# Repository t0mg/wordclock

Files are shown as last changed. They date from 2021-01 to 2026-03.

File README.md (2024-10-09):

# Wordclock
ESP32 based DIY wordclock project

TL;DR: check out this :sparkles:[demo video](https://youtu.be/WF_X5soabm0) :sparkles:

<br/>
Another take on the classic DIY word clock. This one requires a laser cutter but promises a very clean result and is quite cheap to make (about 50 €) while being feature packed with its 11x10 RGB LED matrix, RTC module (time setting survives power loss), light sensor, WiFi connectivity and more. 

This project was designed for the tools available in our makerspace. The largest square that can be cut in an Epilog Mini laser cutter is approximately 30x30cm, so the clock is designed around that constraint.

<br/>
<p align="center">
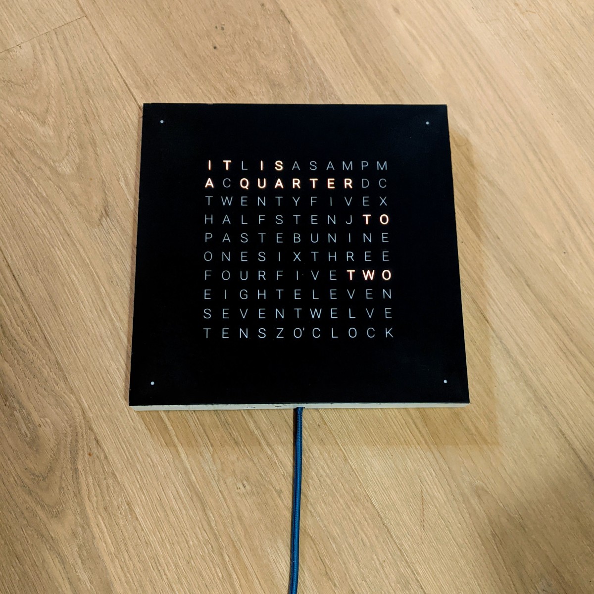
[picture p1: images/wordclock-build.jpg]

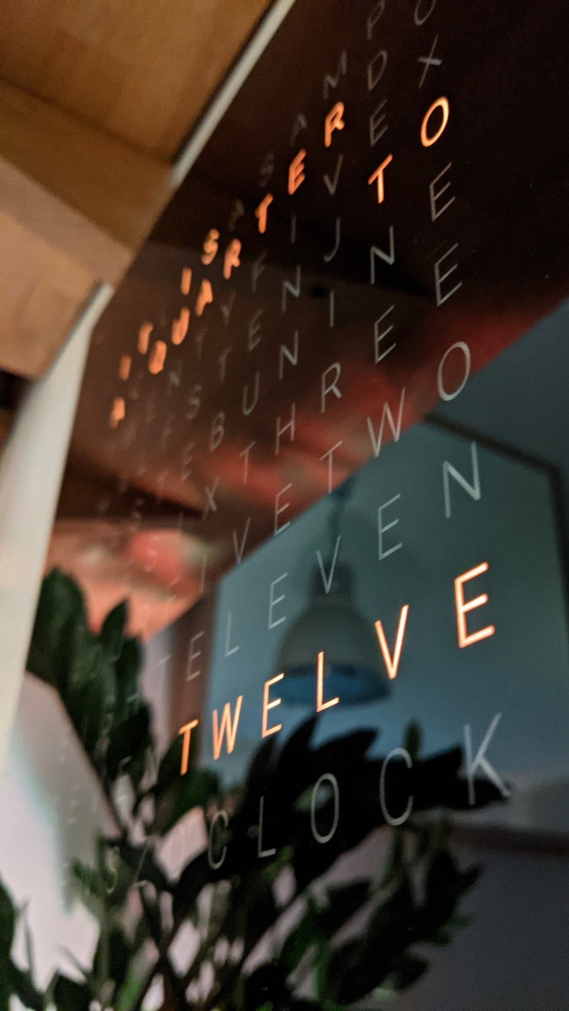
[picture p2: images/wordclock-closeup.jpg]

</p>

## Table of Contents

- [Project overview](#project-overview)
  * [Hardware](#hardware)
  * [Software](#software)
- [Bill Of Materials](#bill-of-materials)
  * [Electronics](#electronics)
  * [Frame](#frame)

## Project overview

### Hardware 

Building the clock from scratch involves mostly laser cutting and soldering. It is not technically challenging if you have basic soldering skills (and access to a laser cutter), but it does take time on both fronts. The project's hardware can be broken down in 3 major elements:

- __The faceplate__ is a glass panel from a cheap picture frame, that is spray painted on its back, then laser etched to mark the letters. The templates and instructions are located in [the faceplate subdirectory](hardware/faceplate/README.md).
- __The frame__ is a sandwich of laser-cut MDF boards. If could also be done with CEC or 3d printing. It holds everything together and most importantly the LED matrix. It has little wells for each LED to channel the light to the letters on the faceplate. The templates and assembly instructions are located in [the frame subdirectory](hardware/frame/README.md).
- __The electronics__ revolve around a WiFI enabled ESP32 development board and a matrix of 114 LEDs made from an LED strip. There is also an RTC module to keep track of time, and a light sensor (LDR). The schematics and instructions for assembly are located in [the electronics subdirectory](hardware/electronics/README.md).

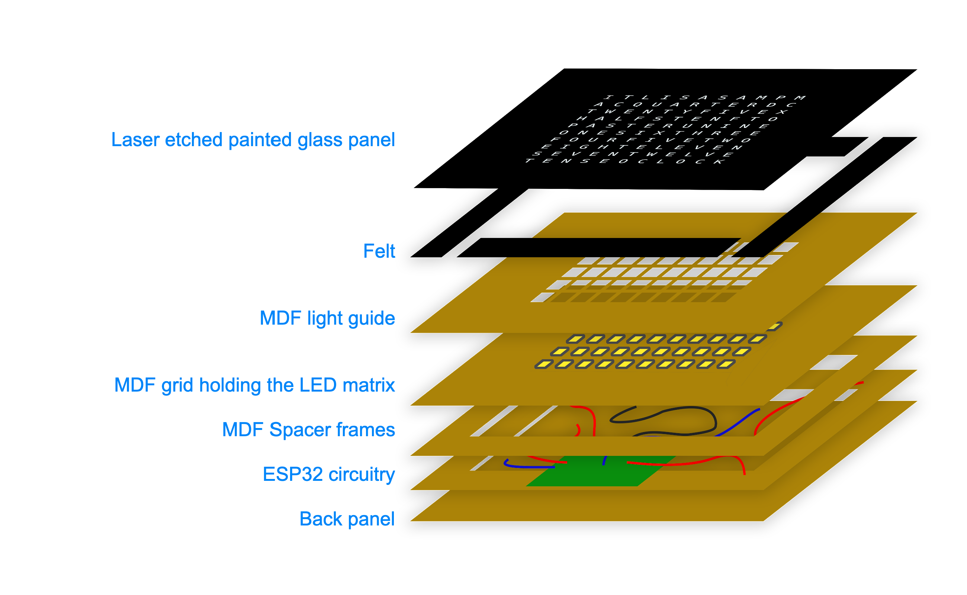
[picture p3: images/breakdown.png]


You can oviously choose to customize any of the provided templates to eg create a different faceplate, or adapt the frame to your specific needs (change the LED layout, add extra sensors, etc).

#### Nodo clock

Alternatively, [nodo-shop.nl](https://nodo-shop.nl) developed and sells [a kit](https://www.nodo-shop.nl/en/52-wordclock) that is fully compatible with the software side of this project. 

The kit includes a 3D-printed faceplate (EN, FR and NL versions available) and custom circuit board, is very simple to assemble and requires no soldering.

<p align="center">
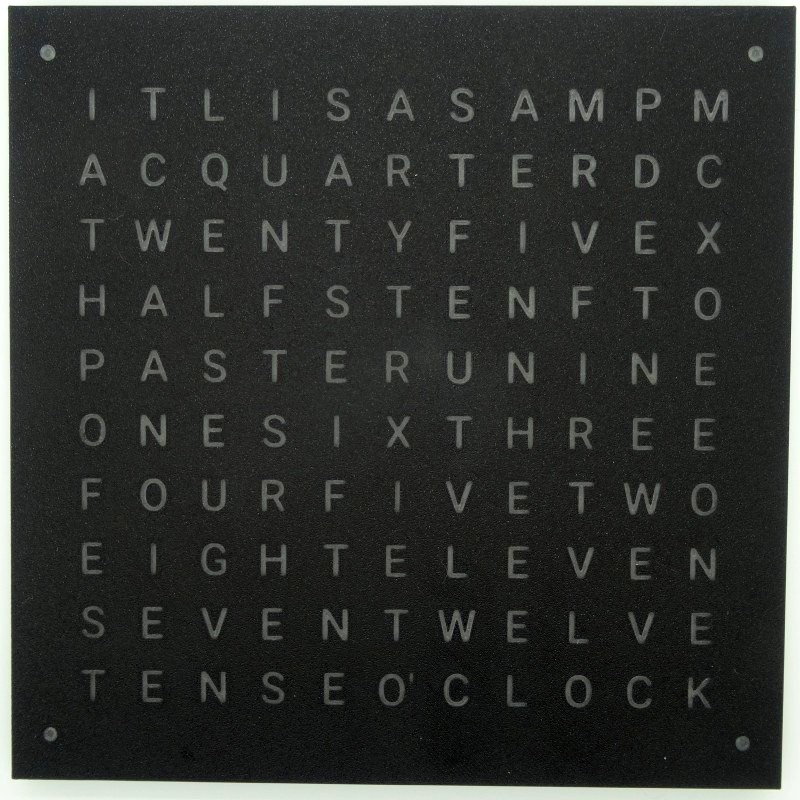
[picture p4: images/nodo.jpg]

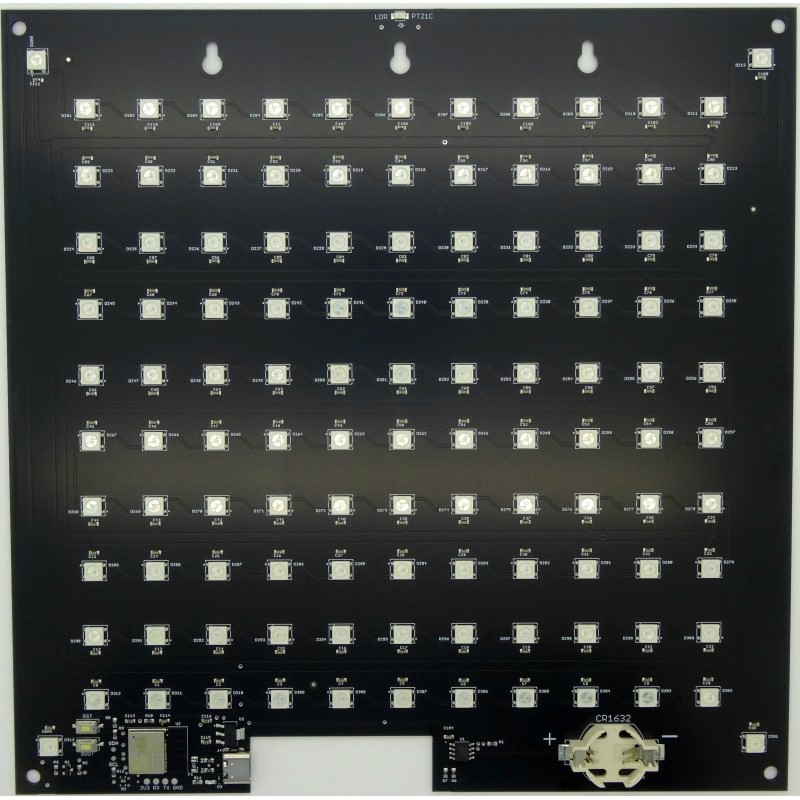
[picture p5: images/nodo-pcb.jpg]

</p>

### Software

The provided [source code](software/README.md) is using [PlatformIO](https://platformio.org/) and Arduino IDE. Here's a [demo video](https://youtu.be/WF_X5soabm0) (from v1.0, does not show all current features).

It runs a web server though a WiFi captive portal for initial configuration via a smartphone or computer, then optionally connects to your home network to use internet time (NTP), MQTT client for home automation, and other features. Check out the [User's Manual](software/UsersManual.md) for more details.

<p align="center">
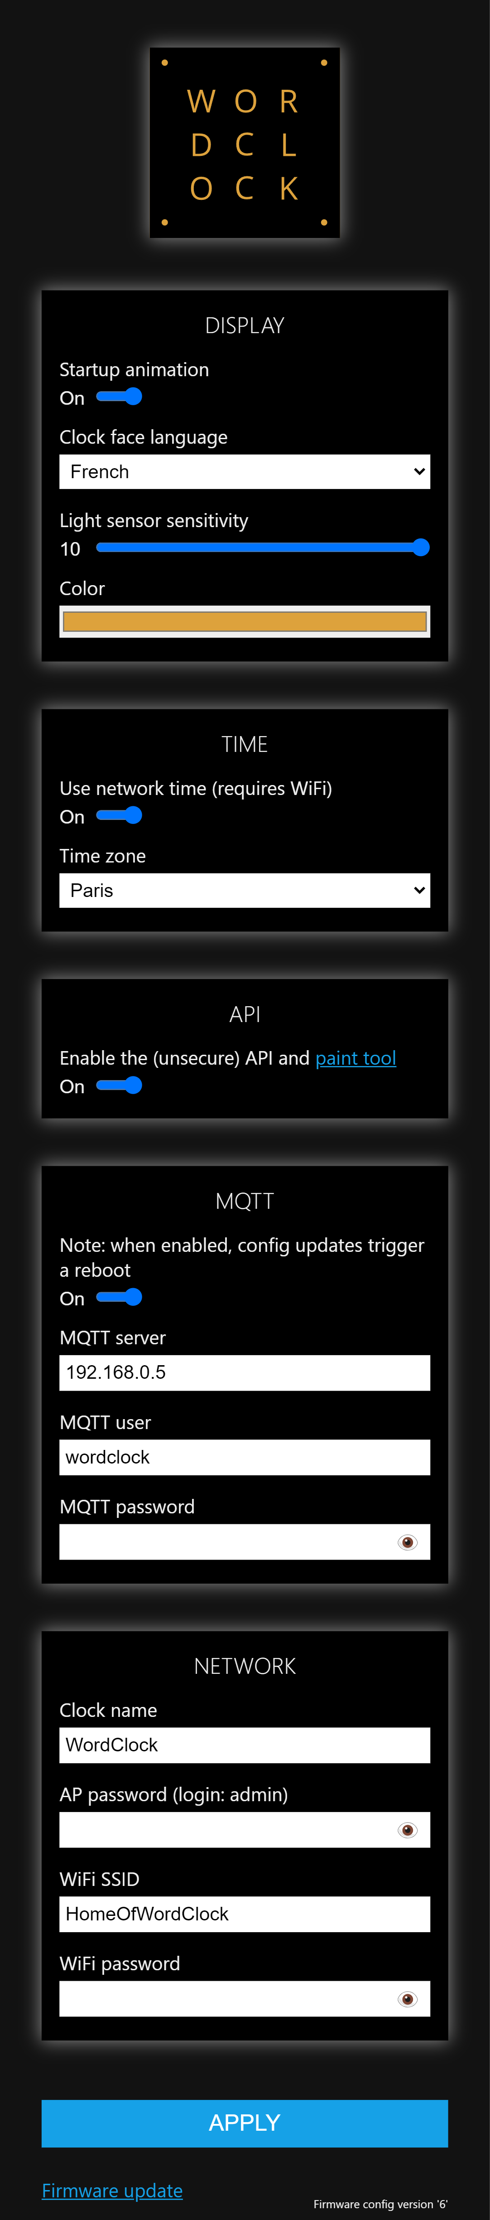
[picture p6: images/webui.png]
Screenshot of the configuration interface
  
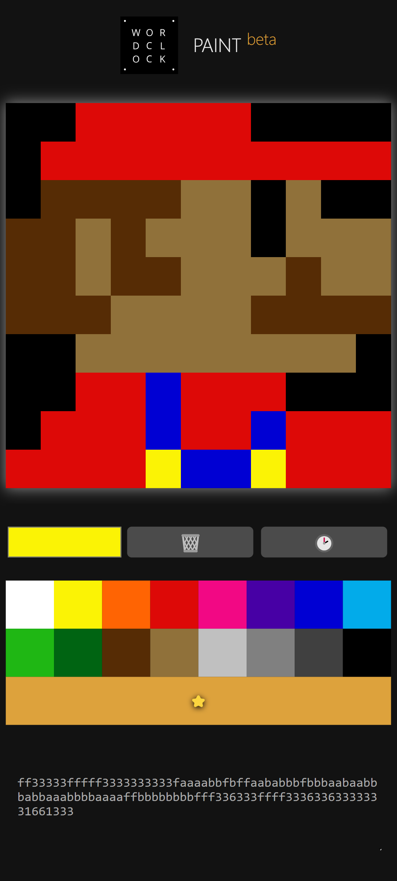
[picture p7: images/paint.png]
Screenshot of the Paint interface
  
</p>

It is, of course, possible to ditch that code entirely and use [ESPHome](https://esphome.io/) or [MicroPython](https://docs.micropython.org/en/latest/esp32/tutorial/intro.html) instead. 

## Bill Of Materials

### Electronics

| Designation | Sample purchase link | Price |  
| --- | --- | ----- |
| ESP32 (WROOM32) microcontroller | [amazon.fr](https://www.amazon.fr/gp/product/B06XWVS2SJ/ref=ox_sc_act_title_6?smid=A3OY00ITR6XRNR&psc=1) | 5,99 € |
| DS3231 RTC module | [amazon.fr](https://www.amazon.fr/gp/product/B07DK5M5VW/) | 3,66 € |
| Level shifter 3.3 -> 5v | [amazon.fr](https://www.amazon.fr/gp/product/B07LG6RK7L) | 0,80 € |
| RGB addressable LEDs (WS2812), 60 per meter, 2 meters roll | [aliexpress.com](https://www.aliexpress.com/item/32958709980.html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) | 4,17 € |
| 1000 uF capacitor | [amazon.fr](https://www.amazon.fr/gp/product/B01M4IUST7) | 0,40 € |
| Power supply (5V, 6A) | [aliexpress.com](https://fr.aliexpress.com/item/32835554243.html) | 6,99 € |
| Female barrel plug | [amazon.fr](https://www.amazon.fr/gp/product/B06XPBKC37) | 0,86 € |
| Light dependent resistor (LDR 5537) | [amazon.fr](https://www.amazon.fr/gp/product/B074QLFCF6/) | 0,08 € |
| Resistor 10k |
| Perfboard | [conrad.fr](https://www.conrad.fr/p/platine-dexperimentation-rademacher-wr-typ-908-1-vk-c-908-1-ep-epoxy-l-x-l-80-mm-x-50-mm-35-m-pas-254-mm-1-pcs-527309) | 3,36 € |
| Breakaway header pins | [amazon.fr](https://www.amazon.fr/gp/product/B07C3W8DGZ/ref=ppx_yo_dt_b_asin_title_o03_s00?ie=UTF8&psc=1) | 0,14 € |
| Wiring (silicon coating is recommended) |
| Solder |  
| Kapton + Electrical tape |
| Heatshrink tubing |
| Hot glue gun + glue sticks |

### Frame

| Designation | Sample purchase link | Price |  
| --- | --- | ----- |
| MDF boards, ~30.5 cm by 30.5+ cm, 3mm and 6mm thick | 615mm x 310mm boards, cut at Leroy Merlin | 5€ |
| Picture frame with glass panel, 30 by 30 cm | [leroymerlin.fr](https://www.leroymerlin.fr/v3/p/produits/cadre-clip-30-x-30-cm-e1500701594) | 2,99 € |
| Wood glue |
| Clamps |
| Spray paint (acrylic) |
| Edgeband |
| 1mm black felt layer | [amazon.fr](https://www.amazon.fr/dp/B07LFJNLZ9/) | 1,11 € |
| Ultra low profile VELCRO® strip or similar | [amazon.fr](https://www.amazon.fr/dp/B0728LKFGM/ref=pe_3044141_189395771_TE_dp_1) | 26 € |
| Black adhesive vinyl (just a small sheet) |
| Copper tape 51mm X 20m (optional) | [amazon.fr](https://www.amazon.fr/gp/product/B01MTQA0O6/ref=ppx_od_dt_b_asin_title_s00?ie=UTF8&psc=1) | 18,98 € |

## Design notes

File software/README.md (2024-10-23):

# Software

This section of the [Wordclock project](../README.md) covers the software running on the clock's ESP32. This page covers the basic features and how to build and deploy from source.

For detailed usage instructions, please refer to the [User's Manual](UsersManual.md).

## Features

- Supports English, French, Italian and Dutch clock faces
- Web interface over WiFi with captive portal for initial WiFi configuration (see [User's manual](UsersManual.md) for details)
- Can use network time (NTP) or manual setting
- Interface offers various other options such as display color, light sensor sensitivity, and [OTA firmware update](#ota-update)
- [MQTT client](UsersManual.md#mqtt-client) to control the clock via home automation platforms such as [Home Assistant](https://www.home-assistant.io/)
- Go beyond time display with [text scrolling](UsersManual.md#text-scroller) and an experimental web interface for real-time [painting](UsersManual.md#paint)

## Demo video

[Here's a video](https://youtu.be/WF_X5soabm0) showing the Wordclock with 1.0 firmware and its web interface in action. New features were added since, such as MQTT and Paint.

## Flashing over USB with the Wordclock Flasher utility

[Wordclock Flasher](https://t0mg.github.io/wordclock-flasher/) is a web based companion tool that can be used to flash the Wordclock over USB with a prebuilt release firmware.

If you have not flashed your clock before, it is the fastest and easiest way to get there. Once you have flashed your device for the first time, the recommended path for upgrading is to use [OTA updates](#ota-update).

### Wordclock Flasher instructions
- Head over to the [Wordclock Flasher website](https://t0mg.github.io/wordclock-flasher/) using Chrome, Edge or another [Web Serial compatible browser](https://caniuse.com/web-serial)
- Press the `CONNECT` button, a system dialog appears to select a serial interface
- Connect your Wordclock to your computer over USB and a new entry should show up in the dialog. Select that and confirm
- The interface should identify your clock based on the chip it uses ([original DIY project](../README.md#hardware), or Nodo kit from [nodo-shop.nl](https://www.nodo-shop.nl/en/52-wordclock)) and display a list of available firmware files
- Click `FLASH`

## Release binaries

If you are not interested in modifying the source code, you can find prebuilt binaries [here](https://github.com/t0mg/wordclock/releases) that can be flashed on your ESP32 with [esptool.py](https://docs.espressif.com/projects/esptool/en/latest/esp32/esptool/flashing-firmware.html) or even directly from Chrome browser with [esptool-js](https://espressif.github.io/esptool-js/)

Use the `firmware_esp32dev` files if you have a custom built clock based on the ESP32 Dev board, or the `firmware_nodo` files if you purchased a [nodo clock kit](https://www.nodo-shop.nl/en/52-wordclock) (which is powered by an ESP32-C3 chip and has the LEDs laid out in a different order).

## Build with PlatformIO

This is the recommended method as it makes it easy to manage dependencies and build for a specific flavor of ESP32. If you do not want to use PlatformIO, see [below](#deprecated-build-with-arduino-ide) for detailed instructions.

1. [Install PlatformIO and VS Code](https://docs.platformio.org/en/latest/integration/ide/pioide.html)
2. Load the project in VS Code (select the folder containing `platformio.ini`)
3. Verify that the target board in `platformio.ini` matches your ESP32 hardware
4. Build and upload

**Important**: Platform IO builds and flashes multiple bin files (bootloader, partition, firmware). To merge those into a single binary for flashing separately from e.g. esptool or the OTA updater, run `pio run -t mergebin` from a PlatformIO console and look for the file ending with "merged.bin" in the `.pio/build` folder.

## OTA update

After the firwmare has been flashed over USB once, you can use the OTA feature to flash further updates: build the new binary file, then open the web portal of your clock, click the `Firmware update` link at the bottom and upload the new `firmware.bin` file. For OTA we don't use the "merged" version mentioned in the previous section.

- Pre-built releases can be found [here](https://github.com/t0mg/wordclock/releases).
- In PatformIO, the build file is located in `.pio\build\<environment name>\firmware.bin`.
- If you are building with Arduino IDE, use `Sketch > Export compiled Binary` to export the file.

__Warning__: if the `firmware config version` displayed at the very bottom of the web interface changes, your settings will be reset. They should otherwise remain.

## [Deprecated] Build with Arduino IDE

_**Note:** this project now relies on PlatformIO features such as board-specific configurations and [binary data embedding](https://docs.platformio.org/en/latest/platforms/espressif32.html#embedding-binary-data), and will therefore **require changes in the code and project files to build with the Arduino IDE**, which is why this section is considered deprecated._

### Add ESP32 boards

If you want to use Arduino IDE only, you need to install the [Arduino core for the ESP32](https://github.com/espressif/arduino-esp32). To do so, the preferred method is to use the Boards Manager and is detailed [here](https://github.com/espressif/arduino-esp32/blob/master/docs/arduino-ide/boards_manager.md).

Once installed, select the ESP32 board from `Tools > Board > ESP32 Arduino > ESP32 Dev Module` (or whatever is most appropriate for your specific board).

You will also need to rename the `wordclock.cpp` file to `wordclock.ino`.

_Note: you might also need to install the appropriate USB driver for your ESP32 board (for example if it has a CP210x USB to UART bridge, it's [this one](https://www.silabs.com/developers/usb-to-uart-bridge-vcp-drivers))._

### Add required dependencies

This project relies on several additional libraries that need to be installed in the Arduino IDE. Open the Library Manager (`Tools > Manage Libraries...`), then search an add the following:

- [RTClib](https://github.com/adafruit/RTClib) by Adafruit
- [IotWebConf](https://github.com/prampec/IotWebConf) by Balazs Kelemen
- [NeoPixelBus](https://github.com/Makuna/NeoPixelBus) by Michael C. Mille
- [arduino-mqtt](https://github.com/256dpi/arduino-mqtt) by Joël Gähwiler

You are now ready to compile and flash the `wordclock.ino` sketch.

## Credits

A large part of this source was based on the code from these two projects (both of which were written for the same hardware) with their explicit permission:
- https://github.com/e-noyau/wordclock (for the clockface and overall architecture)
- https://bitbucket.org/gliktaras/word-clock (for the configuration portal)

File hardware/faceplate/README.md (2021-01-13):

# Faceplate

This section of the [Wordclock project](../../README.md) covers the glass faceplate. For final assembly with the frame, see [here](../frame/#wordclock-assembly).

To create the faceplate, we need to paint one side of the clear glass square we got from the picture frame (see [BOM](../../README.md#bill-of-materials) ). It's the backside of the clock's faceplate. 

We will then laser-etch the inverted letters on the painted side, removing the paint (and slightly frosting the glass in the process). 

## Table of Contents

- [Painting the glass](#painting-the-glass)
- [Vector template files](#vector-template-files)
- [Custom template](#custom-template)
  * [Creating a faceplate template from scracth in Inkscape](#creating-a-faceplate-template-from-scracth-in-inkscape)
- [Notes for using Visicut](#notes-for-using-visicut)
  * [Mirror before etching](#mirror-before-etching)
  * [Etching the template](#etching-the-template)
  * [Final advice](#final-advice)

## Painting the glass

Several options were tested for this project:

1. Acylic spray paint (preferably onw that can stick to glass, [example reference](https://www.amazon.fr/edding-e5200-peinture-toutes-surfaces/dp/B06XRDN8MK))
2. Acrylc surface primer applied with an airbrush ([example reference](https://www.amazon.fr/Vallejo-Surface-Primer-73602-Black/dp/B07VT9LFSH))
3. Acrylic paint applied with a roller (not recommended: the coat is too thick and uneven for the etching to work efficiently)

Options 1 and 2 have been tested and work well. Spray can is the easiest and fastest method, but can produce toxic exausts. If the paint is not explicitly designed for glass, it might still work could peel off with time.

Clean the glass plate very carefully prior to painting it, making sure you remove any dust, as dust specks might get stuck between the glass and the paint coat, which will be quite visible from the other side.

:warning: _Be careful about safety requirements. Check the recommendations for the paint you chose. Wear a mask and paint in a well ventilated area._

## Vector template files

The project currently has classic templates for English and French languages.

Both templates contain at least one of each letter of the latin alphabet, so that the LED matrix could be used as a ouija board to display messages (with appropriate software).

<table>
  <tr>
    <th>Language</th>
    <td>English</td>
    <td>French</td>
  </tr>
  <tr>
    <th>Preview</th>
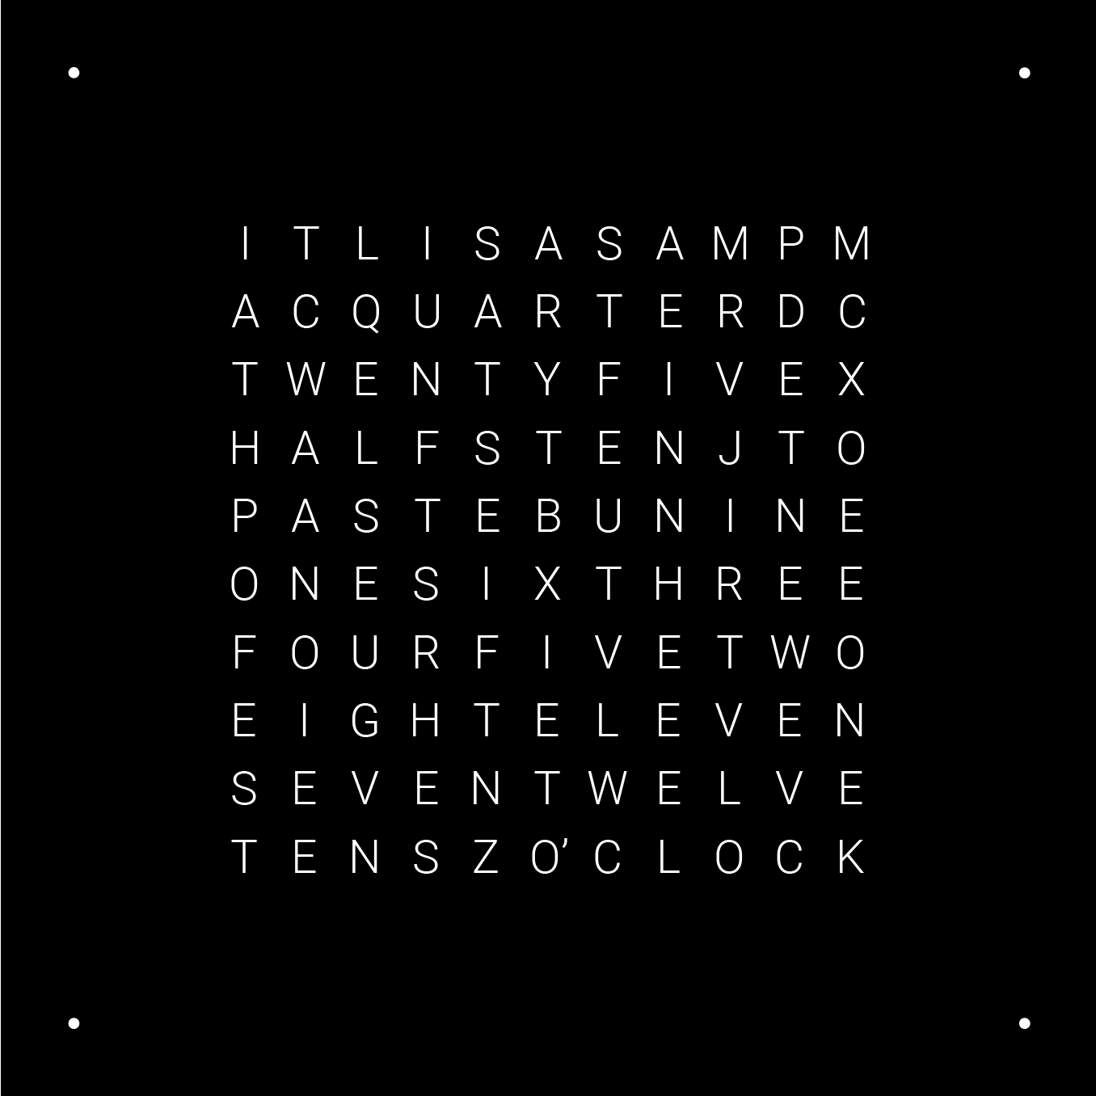
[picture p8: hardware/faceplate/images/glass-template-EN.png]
    <td align="center"></td>
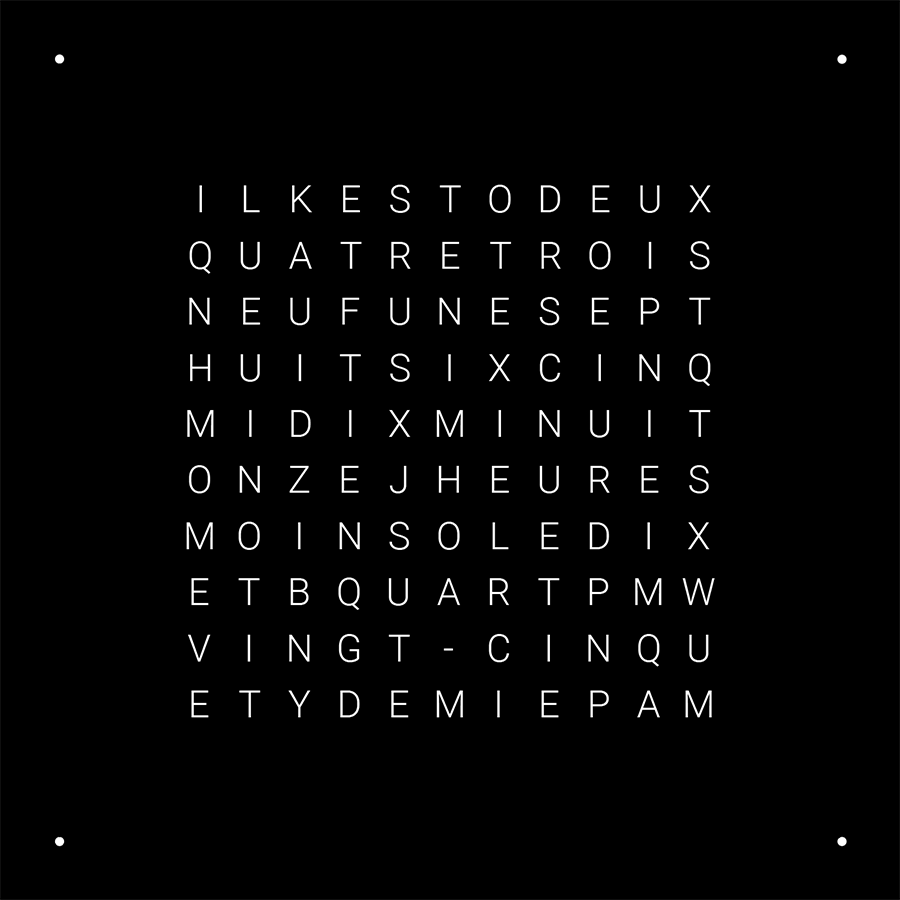
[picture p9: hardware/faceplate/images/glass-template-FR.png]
    <td align="center"></td>
  </tr>
  <tr>
    <th>Ready to etch (scaled, outlines, mirrored)</th>
    <td><a href="glass_template_EN_mirrored.svg">glass_template_EN_mirrored.svg</a></td>
    <td><a href="glass_template_FR_mirrored.svg">glass_template_FR_mirrored.svg</a></td>
  </tr>
  <tr>
    <th>SVG file, scaled (font, see below)</th>
    <td><a href="glass-template-EN-font.svg">glass-template-EN-font.svg</a></td>
    <td><a href="glass-template-FR-font.svg">glass-template-FR-font.svg</a></td>
  </tr>
</table>

## Custom template

If you wish to create a custom template you can use the SVG files above as a starting point, or rebuild it from the MDF Cut2 frame template (from the [frame building instructions](../frame/README.md)). 

The second set of SVG files provided in the table above come with letters as vector text (using Roboto Light font by Google, which can be downloaded [here](https://fonts.google.com/download?family=Roboto) for easier editing. You'll need to install this font if you want to edit the template), and you'll have to convert the letters into outlines and mirror the file prior to sending it to the etching software. The changes you can do from these files are limited and it might be necessary to create a template from scratch, as explained below

### Creating a faceplate template from scracth in Inkscape

1. Download the [SVG file for the front layer of the clock](../frame/wordclock_frame_cut2_template_6mm_sheet.svg) and open it in Inkscape.
2. Ungroup (using the right click menu) the drawing until you can access individual square cutouts for the LED matrix.
3. Add letters to the squares that you want. Make sure to position them consistently within each square, for example by snapping them to the lower-left corner.
4. Create a new layer (Layer -> Add Layer) above the current one, select all of the symbols by shift-clicking on them and move them to the new layer (Layer -> Move selection to layer above). This gives you an easy way to hide the bottom layer that you don't want to engrave and to easily select all of the text to work with.
5. Set your letter font using the font side menu on the right and then use the arrow keys to position your letters. Make sure the vertical alignment is final, horizontally the letters should be near the middle. You should move all of the letters together to maintain consistent character baselines.
6. Select each column of the LED matrix, both squares and letters, and use distribute tool to align the letters horizontally. Operations must be relative to the selection area.
7. Add holes for the corner LEDs: make a copy of a small corner circle, reduce its size and change its fill color to black.
8. To align the filled circles with the corner cutouts, use the distribute tool again, but this time make sure to change "relative to" setting to "Biggest object". Repeat this for the other three corners and move the filled circle to the top layer as described above.
9. Finally, hide the lower layer of the SVG, select all of the characters, convert them to paths (Path -> Object to path) and mirror them horizontally (Object -> Flip horizontally). When you save the file, you will be able to use it with Visicut to engrave your painted glass plate. Flipping the SVG preemptively helps because Visicut truncates the right and bottom sides of the imported drawings, losing the required padding when mirroring.

## Notes for using [Visicut](https://visicut.org/)

Below are specific instructions for using these templates with Visicut software on an Epilog laser cutter.

You can engrave your painted face plate only once, so it’s a good idea to use a discarded piece of wood or cardboard to check the exact alignment of where the plate should be placed inside the laser cutter.

### Mirror before etching

__If you are using the Visicut-ready templates provided above, you can skip this step as the files are already mirrored.__

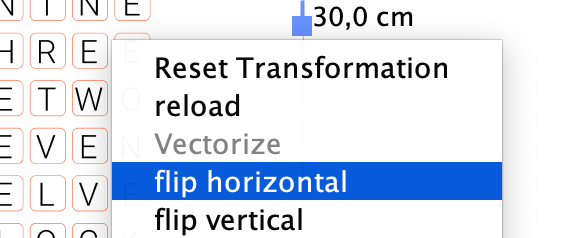
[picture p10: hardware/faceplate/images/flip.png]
 Remember that we are etching the back of the glass panel, so you can either mirror the layout in Illustrator/Inkscape, or directly in Visicut by right-clicking on the drawing and selecting "flip horizontal". It is recommended to mirror your template in your editor rather than doing this later in Visicut.
<br clear="right"/>

### Etching the template

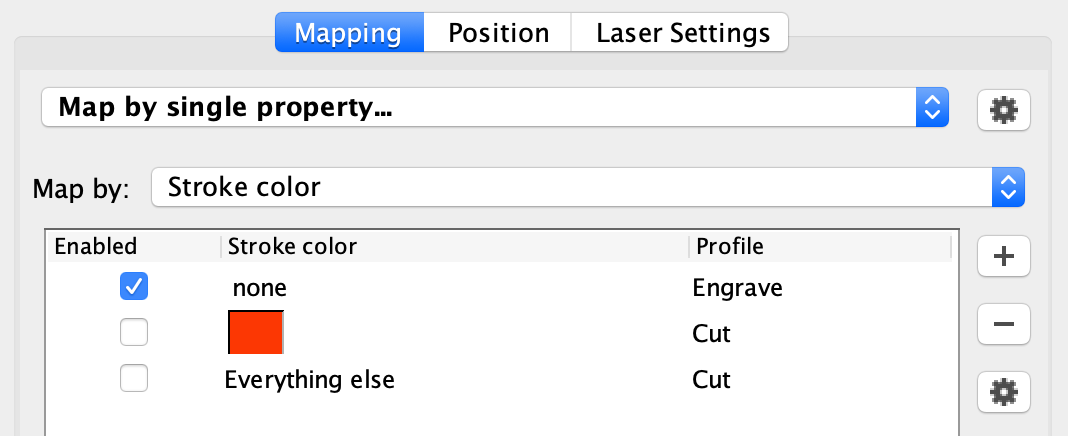
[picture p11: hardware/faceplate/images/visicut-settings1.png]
  The red outline is here to help align the template correctly and __make sure the scale is correct (300x300 mm)__. Once the template has been positioned, use the following settings to only engrave the letters: Map by single property > Stroke color, then only check "none" and select the Engrave profile.
<br clear="right"/>

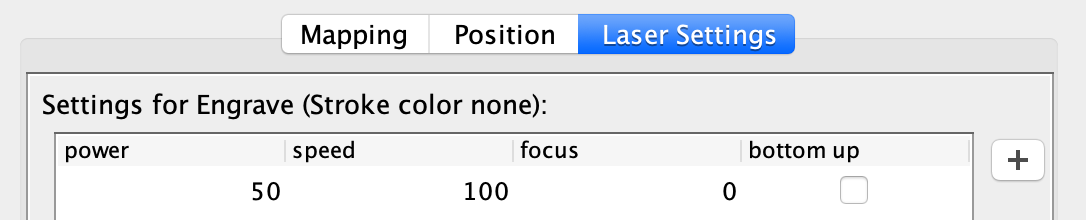
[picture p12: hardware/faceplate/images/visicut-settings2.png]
 Suggested Power and Speed settings for the 40W Epilog Mini are 50-60 for power and 100 for speed. If your paint coat is thick you can bump that up to 80 power (or do multiple passes). 
<br clear="right"/>

Your final preview should look like this:
<p align="center">
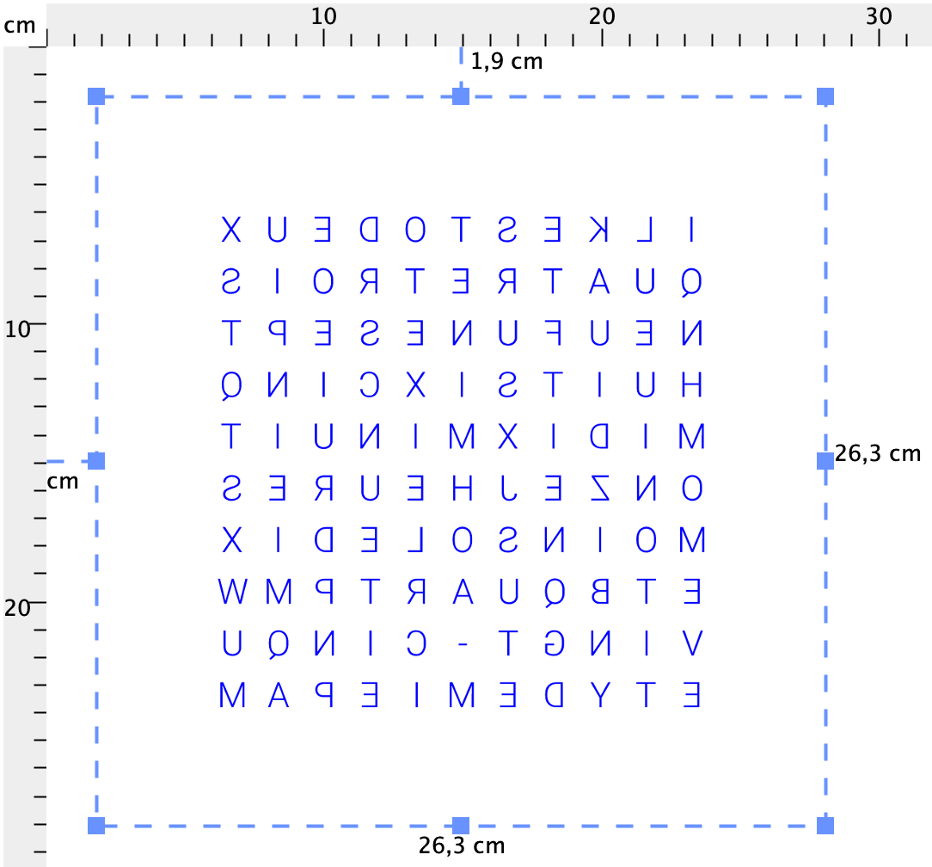
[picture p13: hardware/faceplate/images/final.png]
  
</p>

### Final advice

Carefully inspect the letters on your panel after the first pass. Put a paper towel on the bed of the machine under your glass plate to protect it from scratches and make it a little easier to inspect without moving the glass (which is preferable if you’re going to have to do multiple passes).

Some tiny glass shards might have been created. Although not a huge deal since that side of the panel will not be exposed in the final product, we recommend that you very gently swab the letter with a wet paper towel. In other situations we would have covered the etched areas with tape to mitigate that and cleaned up the glue residue with detergent, but this might damage the paint coat so we’ll do without. Another way to protect the etched side would be to apply a transparent vinyl on the entire surface of the glass.

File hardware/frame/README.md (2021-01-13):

# Frame

This section of the [Wordclock project](../../README.md) covers the laser cut MDF frame of the clock, as well as the [final assembly](#wordclock-assembly) steps.

The frame is made of sandwiched laser cut boards of 3mm and 6mm (6mm max thickness is another constraint of the 40 Watt laser cutter we had).

All MDF layers can be cut out of just 3 boards of approximately 310x310mm, one 3mm thick and the other two 6mm thick. The back panel of the original picture frame (generally 3mm thick low quality MDF) will be recycled as the back panel of the clock, and laser cut to create a hatch.

The layers are glued together using wood glue, the sides of the frames should then be sanded with large grit sandpaper so that some edgeband can be glued to the sides of the frame in order to conceal the various layers.

<p align="center">
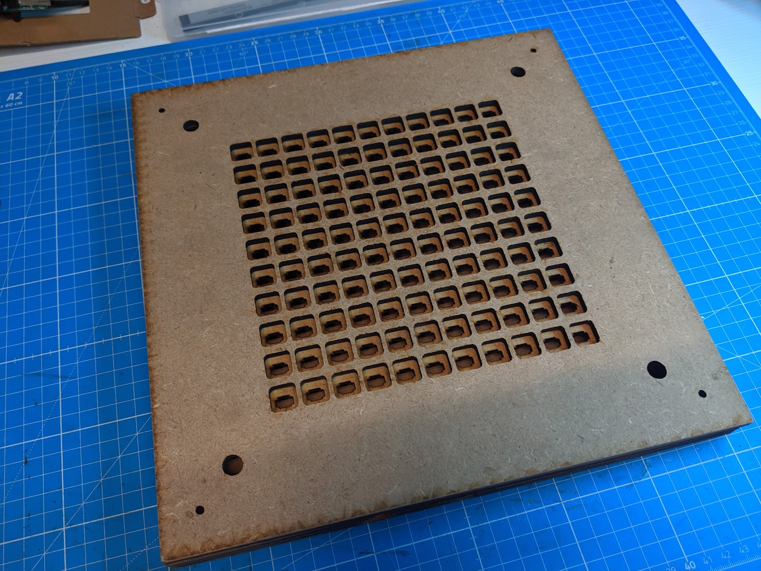
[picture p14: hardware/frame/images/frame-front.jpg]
  
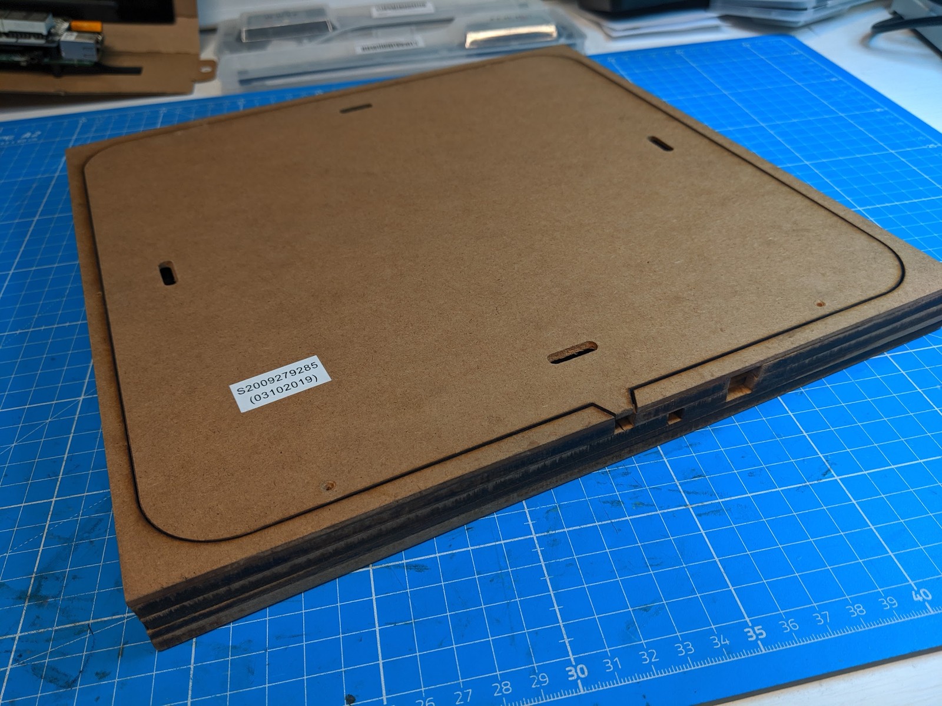
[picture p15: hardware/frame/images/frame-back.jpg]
  
<p>

## Table of Contents

* [Overview](#overview)
* [MDF layers](#mdf-layers)
  + [Light wells](#light-wells)
  + [LED matrix support](#led-matrix-support)
  + [Spacers](#spacers)
  + [Back panel](#back-panel)
* [Laser cutting](#laser-cutting)
  + [Vector template files](#vector-template-files)
  + [Notes for using Visicut](#notes-for-using-visicut)
    - [Back panel template](#back-panel-template)
    - [Cut1 template (310x310x3mm MDF board)](#cut1-template-310x310x3mm-mdf-board)
    - [Cut2 template (310x310x6mm MDF board)](#cut2-template-310x310x6mm-mdf-board)
    - [Spacers template (310x310x6mm MDF board)](#spacers-template-310x310x6mm-mdf-board)
* [Frame assembly](#frame-assembly)
* [Worcdlock assembly](#wordclock-assembly)
  + [Adding touch sensors](#adding-touch-sensors)
  + [Adding the edgebanding](#adding-the-edgebanding)
  + [Adding felt strips and diffuser](#adding-felt-strips-and-diffuser)
  + [Closing the frame](#closing-the-frame)
  + [Attaching the faceplate](#attaching-the-faceplate)

## Overview

Here's a simplified side view showing every layer of the sandwich.

<p align="center">
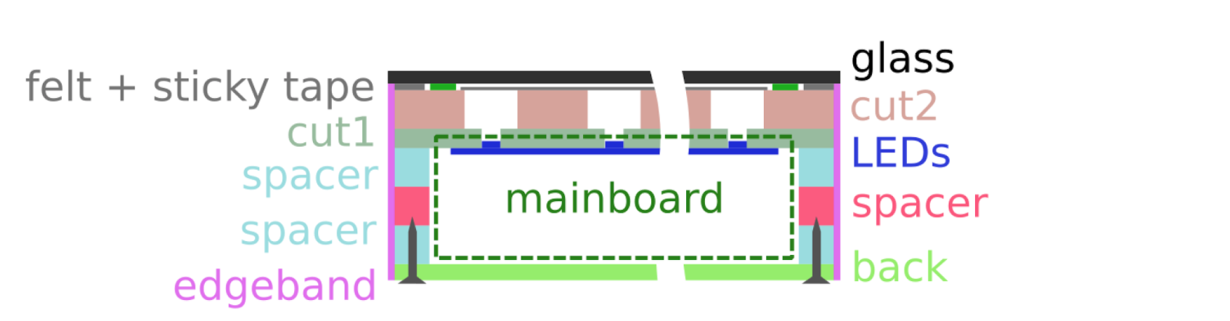
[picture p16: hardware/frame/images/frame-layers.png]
  
<p>

From top to bottom:
- The glass panel aka the faceplate (covered separatley [here](../faceplate/README.md))
- A layer containing an outline made of black felt, some sticky tape or VELCRO® to hold the glass panel to the frame, a paper filter to diffuse the light, and also the capacitive touch sensors.
- The Cut 2 layer (from the 6mm board), tunneling the LED light.
- The Cut 1 layer (from the 3mm board), to which the LED strips are glued (LED matrix assembly is covered [here](../electronics/README.md#led-matrix)).
- 2 or 3 spacer layers (from the 6mm board) to provide a cavity for the mainboard. The bottom side of one of these spacers will be cut out to give access to the light sensor, USB port and power cord.
- The bottom panel, held in place with 4 screws, is the recycled back plate of the picture frame. It is also laser cut.

## MDF layers

Let's have a closer look at every laser cut layer, from top to bottom.

### Light wells

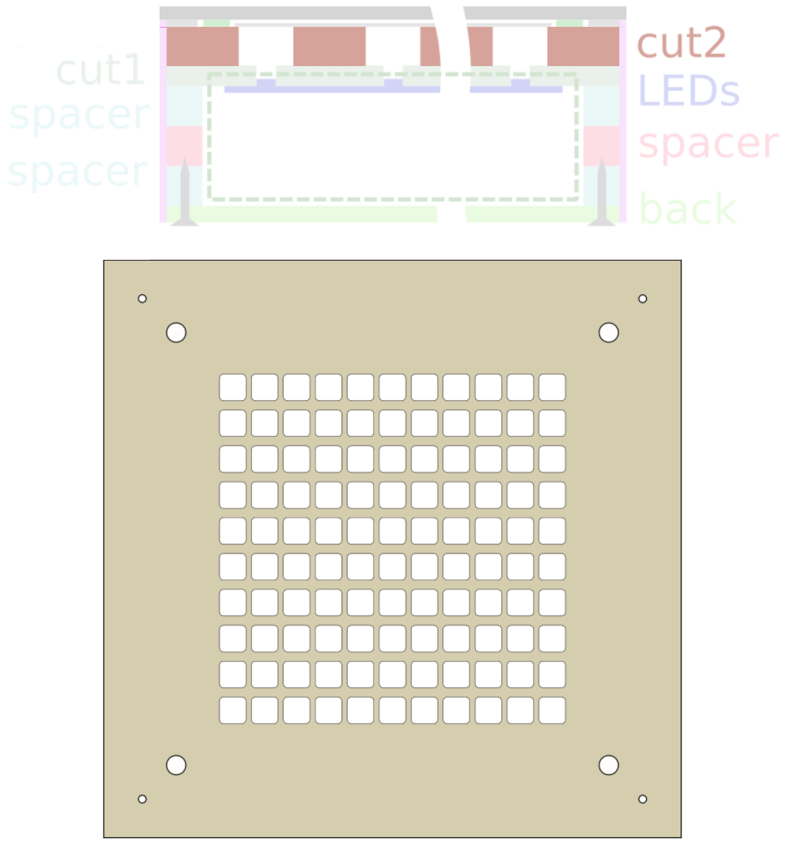
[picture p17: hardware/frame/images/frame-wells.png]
This is the topmost part of the MDF sandwich, which we call the __Cut2__ template.

It is 6mm thick and creates little wells that channel the light of each LED to the characters on the faceplate. A thinner layer with shallower wells would not provide sufficient diffusion and the letters would not be lit up uniformly.
<br clear="left"/>

### LED matrix support

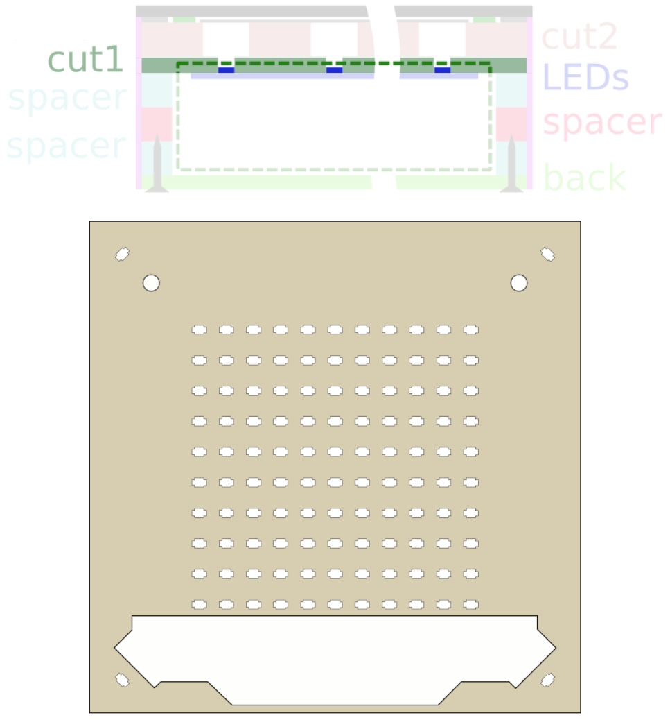
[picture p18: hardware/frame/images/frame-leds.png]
 That's the 3mm thick layer which we call __Cut1__. The LED strips are glued to it. The 50mm tall hole at the bottom provides space for the ESP32 and other electronics.

<br clear="left"/>

### Spacers

<p align="center">
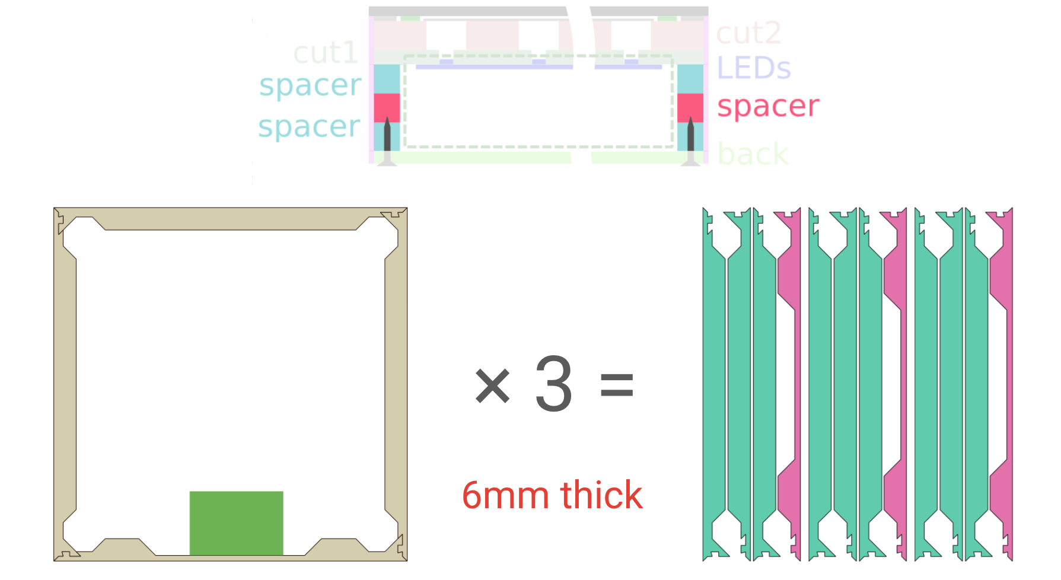
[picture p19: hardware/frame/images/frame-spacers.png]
  
<p>

Spacer layers are empty frames that add thickness to the clock in order to provide room for the LEDs and electronics. Spacer layers can be added at will to make the clock as thick as required. 

In order to save material, the spacer layers are cut down ito thin strips of MDF that can be assembled into a frame. This way we can cut for 3 spacer layers out of a single 30x30cm square (you should only need 2 of these).

The green rectangle in the drawing above represents the location of the 80 x 50mm proto board hosting the ESP32.

### Back panel

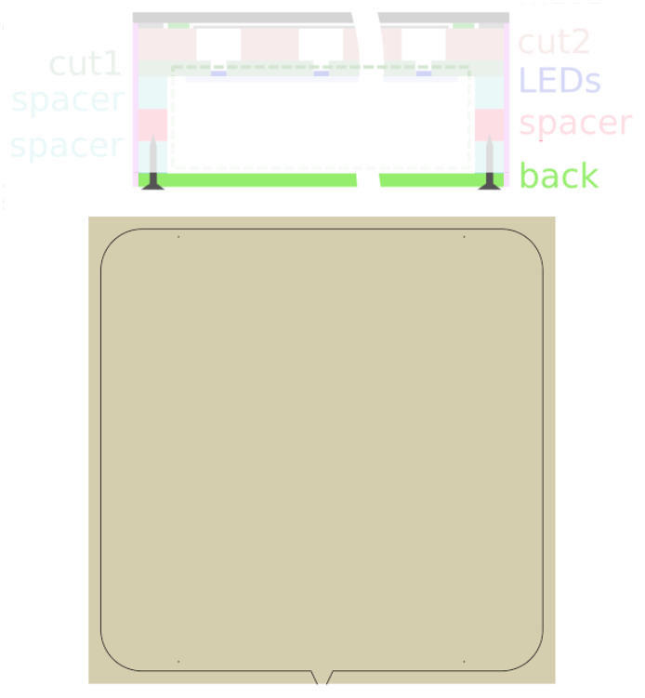
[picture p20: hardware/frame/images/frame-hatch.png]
 We recycle the back of the picture frame and cut a hatch into it. 

The outer rim will be glued to the frame while the center part will be screwed for easy access to the electronics.

<br clear="left"/>

## Laser cutting

### Vector template files

| Layer | Template file | Speed | Notes |
| ----- | --- | ---| ----- |
| Back | [wordclock_frame_back_template.svg](wordclock_frame_back_template.svg) | 15 |  Place the home exactly on the top left corner of the piece. |
| Cut1 | [wordclock_frame_cut1_template_3mm_sheet.svg](wordclock_frame_cut1_template_3mm_sheet.svg) | 14 | Place the home ~2mm from the top and left border of the board. |
| Cut2 | [wordclock_frame_cut2_template_6mm_sheet.svg](wordclock_frame_cut2_template_6mm_sheet.svg) | 14 | Can require require 2 to 3 passes due to thickness, depending on MDF quality. Place the home ~2mm from the top and left border of the board. Manual focus adjustment is needed between passes. |
| Spacers | [wordclock_frame_spacers_template_6mm_sheet.svg](wordclock_frame_spacers_template_6mm_sheet.svg) | 14 | Can require 2 to 3 passes, same as above. |

_Note: speed value is the suggested setting for Epilog Mini 40W, with power at 100._

### Notes for using [Visicut](https://visicut.org/)

Below are specific instructions for using these templates with Visicut software on an Epilog laser cutter.

#### Back panel template
1. Import the file in Visicut.
2. __First__, move the template at position 0,0 in visicut (top left corner of the cutting bed in the preview).
3. __Then__, using "map by single property..." > "map by group/layer", select the black cut line only (this layer is called "cut me"). The green outline and text should disappear from the preview.
4. In the machine, position the home exactly at the top left of the board.
5. Apply suggested values in the Laser Settings tab (power 100 / speed 15).

#### Cut1 template (310x310x3mm MDF board)
1. Import the file in Visicut.
2. Move the template at position 0,0 in Visicut.
3. Set the home ~2 mm from top and left of the board in the laser cutter.
4. Apply suggested values in the Laser Settings tab (power 100 / speed 14).

#### Cut2 template (310x310x6mm MDF board)

1. Import the file in Visicut.
2. Move the template at position 0,0 in Visicut.
3. Set the home ~2 mm from top and left of the board in the Epilog.
4. 6mm board is hard to cut and will likely require more than one pass:
- 1st pass: use 14 speed / 100 power with autofocus option on in Visicut.
- 2nd pass: we’ll use the same speed/power but disable the autofocus and use manual focus to bring the board ~3 mm closer to the laser head, here are the setps for the Epilog Mini :
  * Delete the previous job (trashcan button on the control panel).
  * Unlock the laser head if needed (x/y unlock) but DO NOT set the home again.
  * Press manual focus mode button at the bottom right of the Epilog’s control panel.
  * Move the bed up with 3 short presses of the up arrow on the control panel.
  * Finally press return (u-turn shaped arrow button).
  * Uncheck “enable auto focus” in Visicut and send (Execute) the job to the Epilog.
  * Press go on the Epilog to start the 2nd pass. <br/> Depending on the cleanliness of the optics, MDF batch your board comes from, planet alignment, tea leaves in your cup and other parameters it might be required to do a 3rd pass. Look at the bottom side of the board, if the cut isn’t fully visible: very carefully put the board back in position. DO NOT change the home settings! Wipe it with a paper towel, add another 1 mm of offset to the focus (bring the table 1mm closer to the laser head) and run the previous job again.

#### Spacers template (310x310x6mm MDF board)
Follow the same steps as for Cut1 above.

## Frame assembly

Start from the top panel (6mm __Cut2__ light wells), then glue each layer one by one using wood glue and clamps. Let it cure for an hour between layers, and repeat with the next layer (first glue the 3mm __Cut1__, then a 6mm spacer frame, then another, possibly a third one, and finally the rim of the back plate).

When adding the first spacer frame, you'll have to cut out the bottom piece to provide access to the USB port and LDR sensor, as pictured below. You'll need to do the same for the power cable in the last spacer.

<p align="center">
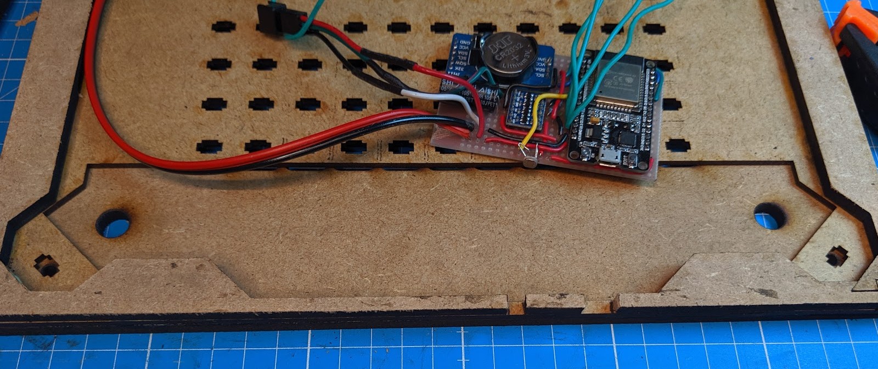
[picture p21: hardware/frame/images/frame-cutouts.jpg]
  
<p>

Sand the edges of the frame to remove the burn marks and smoothen the small misalignments. The edge banding can be applied with an iron but this should be done as one of the last step, once the rest of the build is complete. If you are ready with the [electronics](../electronics/README.md) and [faceplate](../faceplate/README.md), you can proceed with the final assembly.

## Wordclock assembly

These are the final assembly steps once the frame, [electronics](../electronics/README.md) and [faceplate](../faceplate/README.md) are completed.

<p align="center">
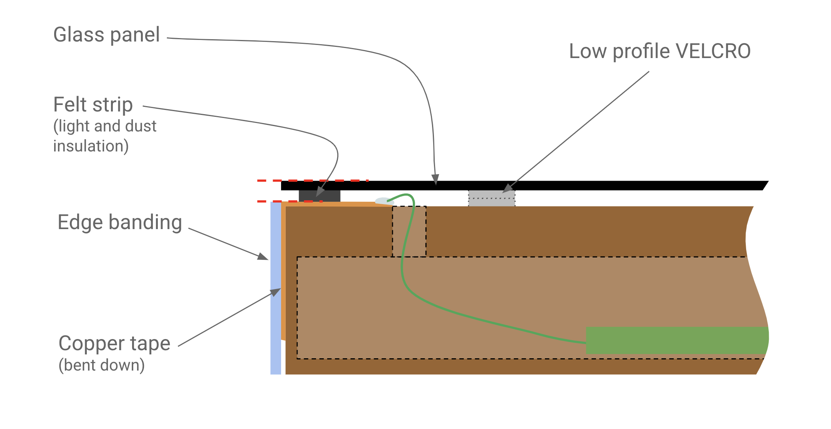
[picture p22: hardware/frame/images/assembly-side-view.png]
  
</p>

### Adding touch sensors

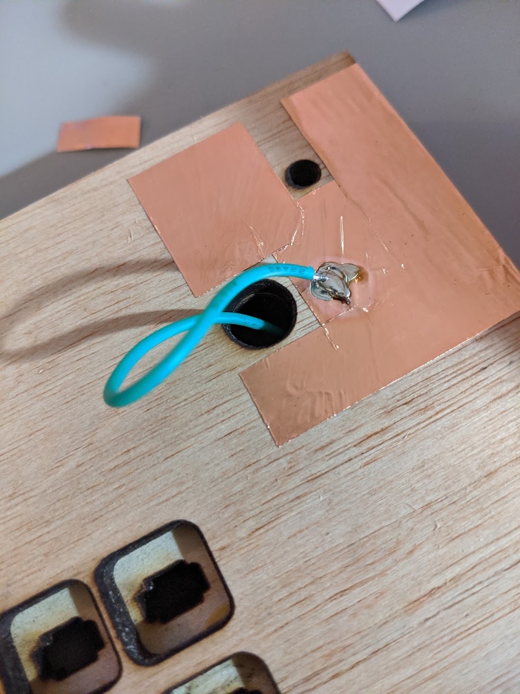
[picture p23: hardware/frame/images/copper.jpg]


__Note:__ This is an optional step. We were not able to get these to work consistently in the software at the time of writing. But it's easy to do if you have copper tape, and needs to be done prior to applying the edgebanding.

1. Take 5-6 cm of copper tape for each corner.
2. Make cutouts if necessary.
3. Bend it around the corners (top and bottom of the vertical edges). Be careful: it’s thin and tears off easily.
4. Leave at least 4 mm of uncovered wood on all 3 sides around the tape  (to make sure that the edge banding will stick).

Optional step of the optional step: solder the touch sensor wires directly on the copper at each corner, wire goes through the 4 holes in your frame. That can be done later when we have software that uses them, but you should still solder the other end of the wires to the circuit board now.

<br clear="left"/>

### Adding the edgebanding

1. Cut 4 strips of white edge banding of ~33 cm each. Be careful, it's brittle.
2. Use a cutter knife and the metal ruler to trim them to your frame’s thickness plus ~10 mm.
3. Use translucent paper to mark the position of the USD/LDR/Power cord holes in your frame, then tape that paper to one your edge bands. Tape the bundle to a piece of wood.
4. Use a cutter knife or a powered hand tool to cut the band along your marks.
5. Use the cutting knife and small files to smoothen the edges (that’s easier to do after sticking the banding to the frame).
6. Heat up an iron to 180C.
7. Take a piece of regular letter paper.
8. Align one of the bands with the top edge of the frame. Use clamps to position it securely.
9. Heat up the band with the iron, using the paper to protect it from direct contact. You only need a few seconds. This melts the glue under the edge band and makes it stick to the frame. You can do it in 2 steps (one half at a time, moving the clamps).
10. Use a cutting knife or a dedicated cutting tool to cut off the ends flush. Then cut the edge banding that hangs over the back of the frame. Repeat for the other sides.
11. If necessary, use small grit sanding paper to smoothen the edges.

### Adding felt strips and diffuser

- Add a thin strip of black felt 5mm away from the edge of your frame, on all 4 sides. Use sharp scissors and a ruler to trace and cut the strips. These strips will prevent light from bleeding out of the sides of the frame, and dust to enter in.

- Cut a 21x21 cm square of paper and stick it on top of your frame, to act as a diffusion layer for the the LED light. You can use transfer paper, or no paper at all for brighter (but less diffuse) lights. It is also possible to print a grayscale pattern on the paper to add some texture to the letters.

### Closing the frame

- Use hot glue gun to secure the proto board and ESP32 to the frame. You can also use tiny screws to block it even more securely.

- Use 4 2.5x12 wood screws to lock the back panel in place (the hatch has precut holes).

The DC barrel jack (power cable) is meant to be kept entirely inside of the clock, in order to avoid dangling underneath it. To avoid an accidental pull you can tie a knot, use more hot glue, a zip tie around your cable, or all of the above.

### Attaching the faceplate

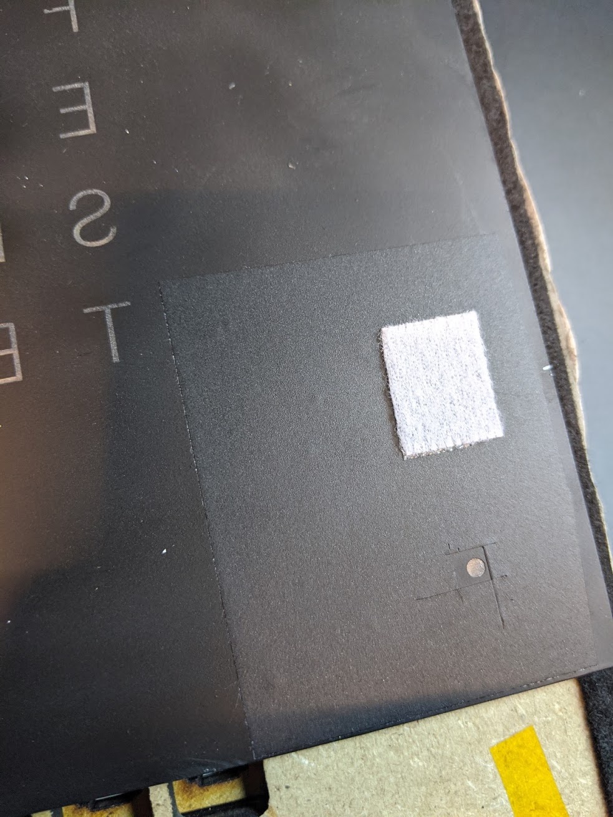
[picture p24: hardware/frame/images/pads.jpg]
 We use small low profile VELCRO® patches in the 4 corners to attach the [glass panel](../faceplate/README.md) to the frame (and make it removable).

Paint is likely to tear off if we stick the VELCRO® directly to it, so we use a large piece of black vinyl to cover the back (with a hole for the corner LED).

You can also cut a 4 little pieces of paper to diffuse the corner LEDs. and sandwich them between the vinyl and the glass (not pictured).

To apply the (very strong) low profile VELCRO® tape:
1. Cut the bits from the VELCRO® roll. The bits that will on the glass __must be half the size (~2cm)__ of those that will go on the frame.
2. Peel off the tape and stick the longer bits on each 4 of the frame’s corners (don’t cover the LED hole). Press firmly and __let it cure for 10 mn__. 
3. Position the smaller bits on the large ones, then peel off the tape and place the glass on top carefully. Press firmly and __let it cure for another 10 mn__. You can do each corner one by one or all at the same time.

<br clear="left"/>

<br/><br/>
Congratulations, your Wordclock build is now complete !

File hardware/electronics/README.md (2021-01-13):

# Electronics

This section of the [Wordclock project](../../README.md) covers the wiring of the electronics and the LED matrix.

## Circuit

See [here](../../README.md#bill-of-materials) for components list. 

Everything fits fairly easily on the proto board which is 80mm x 50mm. It is possible to make it wider than 80mm, but the short side (50mm) is physically constrained by the frame. Thickness must also kept to a minimum (the clock module is probably the thickest part with its battery holder).

<p align="center">
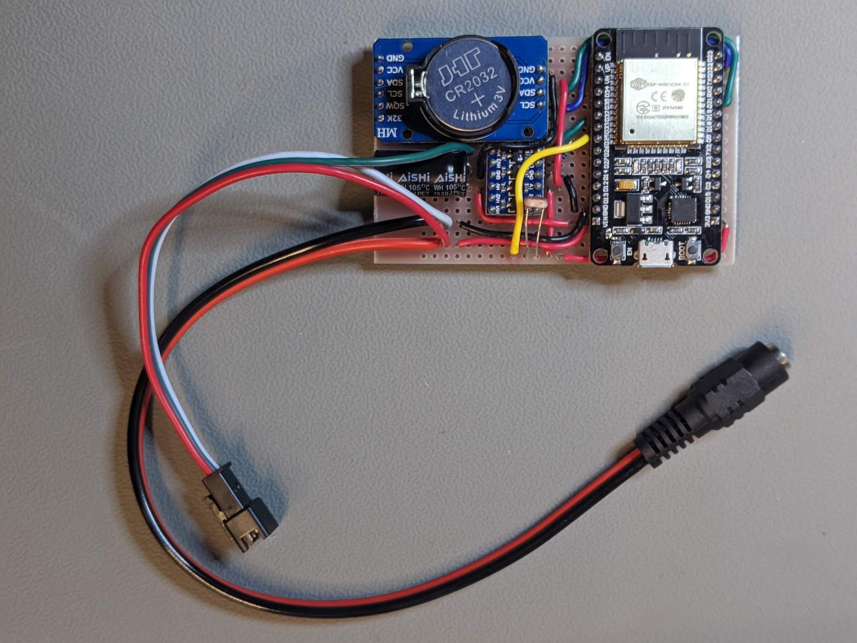
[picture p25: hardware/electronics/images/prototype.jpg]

</p>

:warning: _This prototype uses a 30 pin ESP32 board, and in this picture it had the LDR incorrectly wired to GPIO 25_

### Schematic

<p align="center">
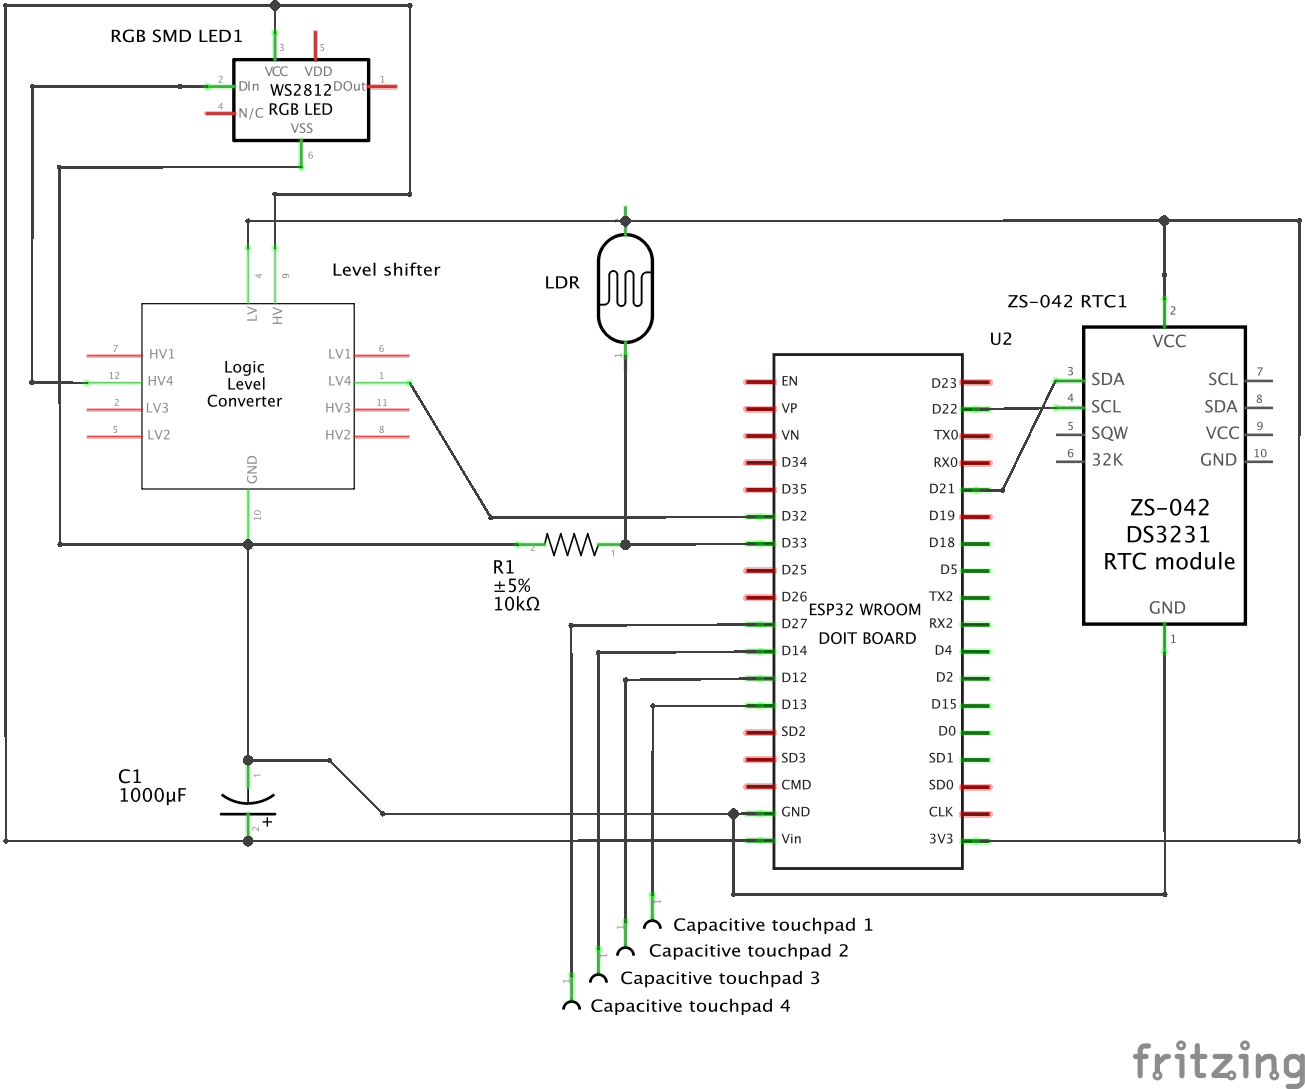
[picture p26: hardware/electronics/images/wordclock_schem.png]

</p>

- Power is provided through a DC jack by an external 5V power supply that we recommend should be able to output 6A. This is necessary to provide enough current to light up all 114 RGB leds at full brightness. This is not strictly necessary with the base function of the clock, but provides legroom for alternate uses of the LED matrix. If powering the circuit through the ESP's USB port instead, be careful not to light up more than a handful of LEDs at a time.

- The ESP32 board illustrated here has 36 pins. There are many alternate ways of wiring this circuit as we are not using every available pin. There are also 30p pin ESP32 dev boards wich should work with the same wiring. You can check this great [pinout reference on randomnerdtutorials.com](https://randomnerdtutorials.com/esp32-pinout-reference-gpios/) if you need to make changes. 

- DS3231 is a temperature compensated I2C clock operating at 3.3V. It'll keep track of time with decent accuracy and its CR2032 backup battery prevents the time setting from being reset due to power loss. It's connected to the ESP32 via the default SDA and SCL GPIO pins (21 and 22). This module is actually optional since the ESP32 can get the time via NTP over WiFi, but with it, it works as a regular wall clock that doesn't need an internet connexion to operate.

- The level shifter boosts the signal sent from GPIO pin 32 to the LED matrix from 3.3 to 5V (only the first LED is represented on the schema, the remaining 113 are simply daisy chained behind it). While the level shifter might not be necessary depending on your LED strip, it is very cheap and doesn't hurt either way. More info [here](https://learn.adafruit.com/neopixel-levelshifter/shifting-levels).

- The C1 capacitor is here to protect the LEDs, it prevents an initial onrush of current from damaging them. See [here](https://learn.adafruit.com/adafruit-neopixel-uberguide/powering-neopixels) for further details.

- The LDR (light sensor) is wired to one of the Analog to Digital Converters (ADC) of the ESP32. We use GPIO 33 but any other GPIO from the ADC1 group will do. Do not use any of the ADC2 pins or you won't be ale to use WiFi simultaneously. R1 is a pulldown resistor.

- Capacitive touchpads are meant to be wired to the 4 corners of the clock. It's a built in feature of the ESP32. At the time of writing, we were not able to get this to work consistently and are not using them but they're here for information and should be considered optional.

### Breadboard

Here's another view of the circuit, which can be used as an easier reference to place everything on the proto board. The exact way you wire this on the proto board is up to you, but the LDR and USB port of the ESP32 should be exposed on one of the larger sides.

<p align="center">
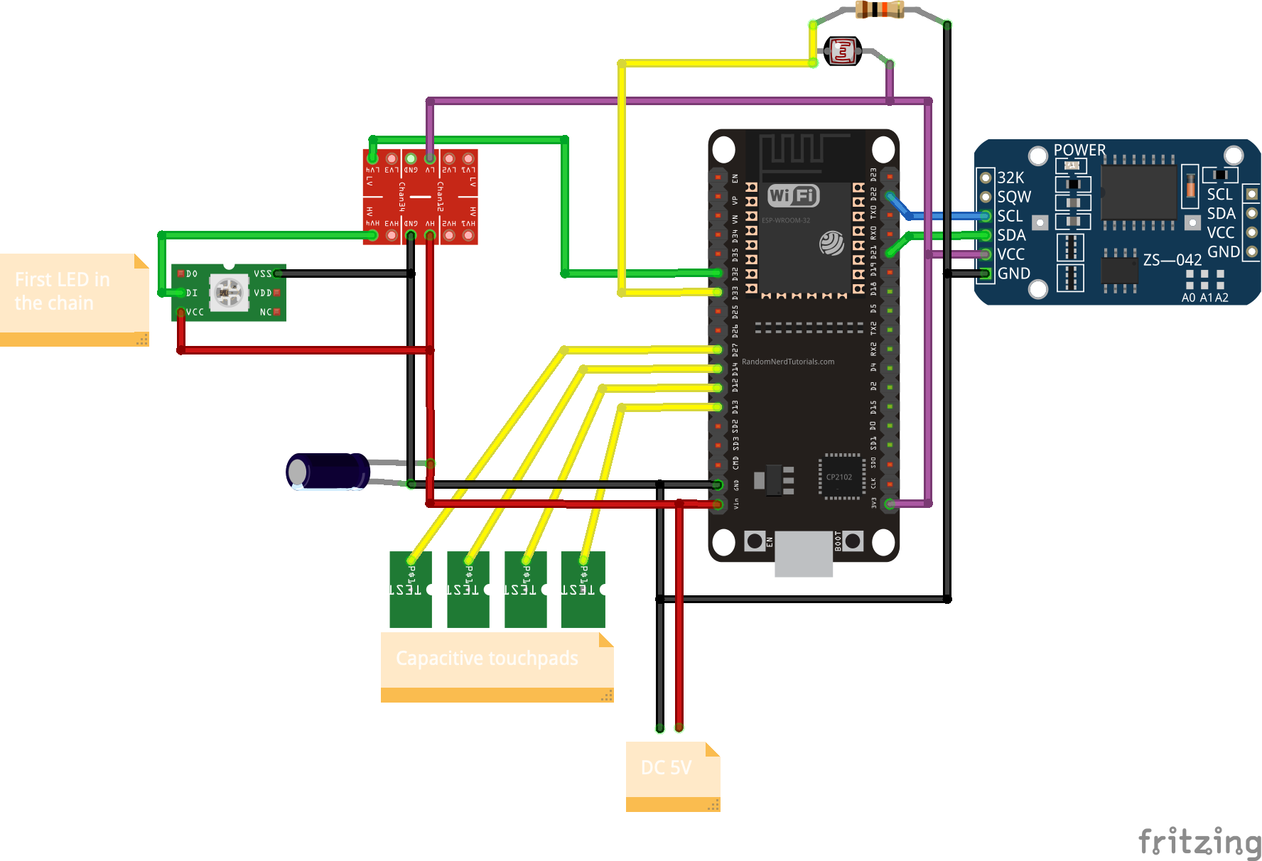
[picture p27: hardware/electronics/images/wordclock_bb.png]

</p>

## LED Matrix

<p align="center">
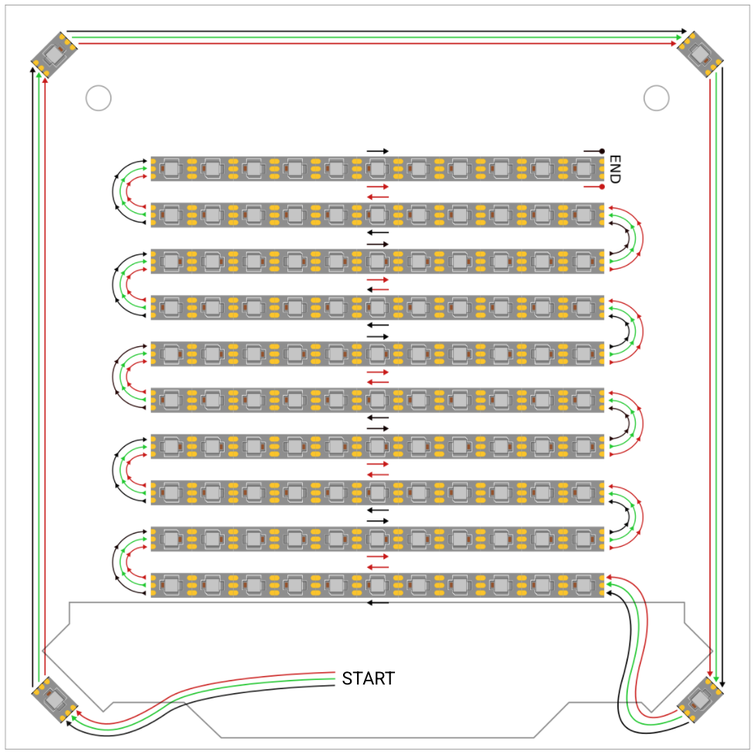
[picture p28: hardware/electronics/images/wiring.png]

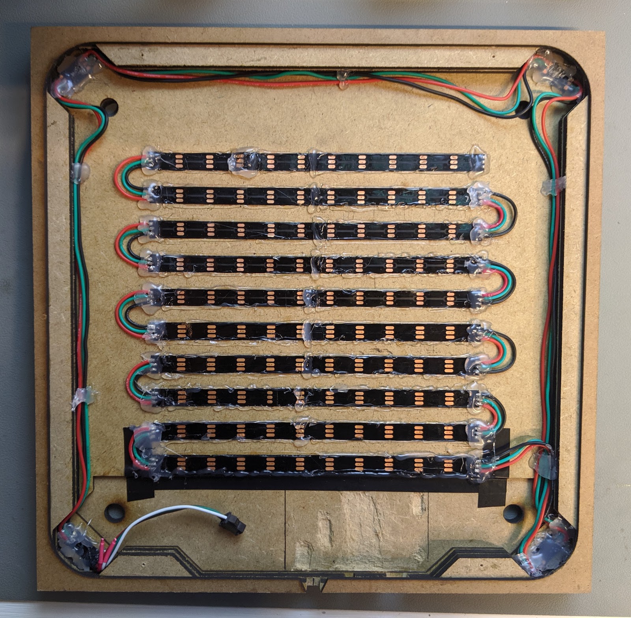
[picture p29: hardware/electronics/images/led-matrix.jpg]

</p>

We use 2 strips of 1 meter with 60 LEDs per meter (12mm spacing or a LED every 0.65"/17mm) which provides adequate spacing for this build. The strips are cut into 10 segments of 11 LEDs which are wired as a daisy chain. At one end of the chain, 4 additional LEDs are placed in each corner of the frame and mark the 4 minutes between text updates (eg from 'quarter' to 'twenty').

The LED modules take +5V (red in the diagram above), GND (black) and DIN (data line, green). It's okay to daisychain everything for simpler wiring, but you might notice slightly dimmer lights towards the end of the chain. For better power distribution, you can feed +5V from the middle of each segment or make small groups of segments. Only the data line actually needs to be daisychained.

Be careful about the orientation of your strips, there are little arrows screenprinted on them. The arrow direction should alternate from one raw to the other (see video link below).

The LED strips are hotglued to the dedicated lasercut support (see the [frame building instructions](../frame/README.md)).

### Assembly video

Here's a [LED matrix assembly video](https://youtu.be/uqOhGHvoc6M).

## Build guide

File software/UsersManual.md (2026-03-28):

# WordClock User's Manual

## First time use

When you are powering the device for the first time after flashing the firmware, it will create its own WiFi Access Point with SSID `WordClock`.

Use your smartphone (or tablet, or computer) to detect the WiFi network, and connect to it by using the password `password` (or `12345678` in the old 1.0 firmware).

## Configuration page (Config portal)

After a successful connection to the Access Point, a configuration page should show up in your web browser (there might be a notification to tap).

It should look a bit like that:

<p align="center">
  
</p>

__Note:__ At this point even if your home network is not configured, the clock is already useable in an offline manner, especially if you have a battery cell and RTC module.

Except for password fields, you will see the item values previously set (or for first time setup, the factory default).

### Password fields

On password fields you will never see any previously set values. You can __reveal a password__ you just entered by clicking the 👁️ (eye emoji). You can then click a second time to hide the text, which is recommended before submitting the configuration form, as browsers might save clear text values to use them as suggestions.

Some fields are protected with constraints, and a validation check is performed. In case there is an error in the validation of any field, nothing is saved and a red message should appear next to the field that caused an error. You will need need to re-enter values for filled-out passwords in this case.

## Configuration options

Here are the available configuration options.

### Network

The Network section will show at the top of the page if it has not been configured before, and will afterwards move to the bottom (as shown in the screenshot above) since it probably doesn't need to change it very often.

-  __Clock name__ - defaults to `WordClock`. It will show up as SSID in Access Point mode (brifely at the beginning of every boot sequence, or if the clock is unable to connect to the configured WiFi network). You shouldn't need to change it unless you are planning to set up multiple clocks and/or use MQTT as it is also used in MQTT topics.
- __AP password__ - this password must be at least 8, at most 32 characters. **DO NOT LOSE IT** or you will need to reflash your clock. The default value is `password`. It is used in 2 situations: 
  - it's the password to the Access Point network created by the clock during intitial setup and subsequent boot sequences. The UI is forcing you to change it at this point, but you can still set it to the same default value if you want.
  - it's also the password to the clock's web interface once it is connected to your home WiFi and you type its IP in a browser (the login to this interface is always `admin`). 
- __WiFi SSID__ - The name of the WiFi network you want the clock to connect to.
- __WiFi password__ - The password of the network above. Note that it is required: open networks are not supported.

### Display

- __Startup animation__ - Enables a short animation when booting. Convenient to control that all LEDs in the matrix are working.
- __Clock face language__ - Selects which language to use for time display. See [ClockFace.cpp](wordclock/src/src/ClockFace.cpp) to check the expected layout for each.
- __Light sensor sensitivity__ - The light sensor can be used to dim the chosen display color when measured ambiant light is low.
- __Color__ - The color used by the clock to display the time. This setting is not modified when changing the color via [MQTT](#mqtt-client) (meaning that clock can return to this value after a reboot).

### Time

- __Use network time (requires WiFi)__ - Enable NTP to retrieve and periodically correct displayed time. Requires Network seettings to be configured to a WiFi network with internet access (as in AP mode the clock can't access NTP servers).
- __Time zone__ - Only shown if network time is enabled. Choose your local timezone from this list.
- __Time__ - When network time is not enabled, the current time can manually be set here. In this mode the clock does not require an internet access nor WiFi to be configured. Time is kept thanks to the coin cell battery powering the RTC chip (meaning you only need to set this once even if you reboot or unplug the clock).

### API

Enables a non password-protected [API](#api-1) and experimental [paint](#paint) web interface.

### MQTT

You can enable the MQTT client and configure your server's adress, login and password here. For more details on this feature, see the [dedicated section below](#mqtt-client).

**Note:** When this is enabled, any configuration changes will cause a reboot of the clock. Therefore it is recommended to turn it off when playing with other settings in order to avoid having to wait for the clock to reboot and reconnect to your WiFi every time.

## Connecting to a WiFi network

When you have successfully set the WiFi configuration fields, the device will try to connect to it.

If the connection fails, the device will __fall back to Access Point
mode__. This means that the device will form its own WiFi network again, to which you can connect to and try to correct the network setup. This time you will see the __Clock name__ value as the access point name (SSID) - `WordClock` if you haven't changed it - and you need to use the __AP password__ that you should have configured previously.

Note that in such a case where the configured WiFi network is not connecting, the device will fall back to Access Point mode only for a few seconds as it will periodically __retry connecting to it__. After all, maybe your configuration was OK and it's your WiFi that was down 🙂.

Once you connect in Access Point mode, it will be kept running as long as any device is connected to it. You'll need to disconnect your device from it for the clock to continue its operation (ie reboot).

## Configuration in connected mode

After the clock successfully connects to the configured WiFi network, the temporary Access Point is terminated, but you can still access the clock using its IP address.

To determine the IP address of your clock, you might want to consult with your WiFi router (it might also be possible to use a local domain such as `wordclock.lan`, `wordclock.home` or `wordclock.local`, but this mostly depends on your router so your mileage may vary).

When you want to access the Config Portal of the clock __via a home WiFi network__ from your web browser, a login prompt will be displayed, where you need to enter:
- User name: `admin`
- Password: the password you have set up previously as __AP Password__ (`password` if you kept the default value).

You will then land on the same configuration interface as seen in Access Pont mode.

#### Security notes connecting from WiFi network

The clock currently doesn't support SSL. To make things a bit more secure and avoid compromission, you can:
- Prefer making config changes in Access Point mode rather than when connected to your home network
- Set up a dedicated WiFi network for your IoT devices

## API

The API is disabled by default because it is not secured. It was created to allow the [Paint](#paint) web interface to work, but could be used directly as well.

When enabled, the following routes are activated:
- `http://<clock IP>/api/color/get` -> returns the HTML code of the currenly set color
- `http://<clock IP>/api/matrix/set/<payload>` -> activates Paint mode and displays the payload, see [Paint](#paint) for details
- `http://<clock IP>/api/matrix/unset` -> exits Paint mode and returns to displaying time
- `http://<clock IP>/api/text/set` -> scrolls a custom text, then returns to displaying time, see [Text scroller](#text-scroller) for details

## MQTT client

MQTT is a lightweight publish-subscribe protocol designed for resource-constrained devices and low-bandwidth networks, commonly used in IoT applications. MQTT clients talk via an MQTT broker (see here for [Home Assistant](https://www.home-assistant.io/integrations/mqtt/) instructions).

The clock's MQTT client can be enabled and configured from the web UI. Note that the clock will reboot after changing any setting if MQTT is enabled.

Topics are prefixed with the name defined as `Clock name` in the web UI settings (but converted to lowercase and with spaces removed). The default prefix is therefore `wordclock`.

### State topics
- `wordclock/availability` -> either `offline` or `online`
- `wordclock/sensor/ldr` -> current raw LDR reading (0-4095), refreshes every 15 seconds
- `wordclock/light/color` -> current color (in `r,g,b` format)
- `wordclock/light/switch` -> current state of the display `ON` or `OFF`

### Command topics
- `wordclock/light/color/set` -> sets the LED color, payload must be an `r,g,b` formatted string
- `wordclock/light/switch/set` -> send `ON` or `OFF` to toggle the display (with a fade effect). The previously set color is restored on `ON`.

#### Matrix paint (experimental)
- `wordclock/light/matrix/set` -> activates Paint mode and displays the payload, a 110 characters string using a preset palette, see [Paint](#paint)
- `wordclock/light/matrix/unset` -> exits Paint mode and returns to displaying time

#### Text scroller (experimental)
- `wordclock/light/text/set` -> activates Text Scroller mode and displays the payload text, see [Text Scroller](#text-scroller)

### Home Assistant configuration

Below is an example configuration for Home Assistant using [light](https://www.home-assistant.io/integrations/light.mqtt/) and [sensor](https://www.home-assistant.io/integrations/sensor.mqtt/) MQTT integrations.

```yaml
mqtt:
  light:
      - name: "Wordclock"
        availability_topic: "wordclock/availability"
        state_topic: "wordclock/light/switch"
        command_topic: "wordclock/light/switch/set"
        rgb_state_topic: "wordclock/light/color"
        rgb_command_topic: "wordclock/light/color/set"
        qos: 0
        optimistic: false
  sensor:
      - name: "Wordclock Light sensor"
        availability_topic: "wordclock/availability"
        state_topic: "wordclock/sensor/ldr"
```

Entities can then be arranged in a dashboard card like this one:

<p align="center">
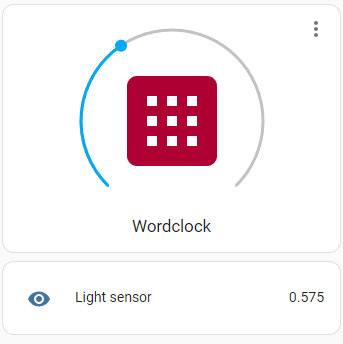
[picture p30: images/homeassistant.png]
Home Assistant card
  
</p>

(the icon used for the button is `mdi:apps-box`)

## Paint

__Note:__ This is an experimental feature. Payload format, palette and APIs might change.

When the [API toggle](#api) is enabled, a web interface becomes available at `http://<clock ip>/paint`.

It is a basic real time drawing tool that allows you to take control of the clock's LED matrix. While it is fun to just play with, it is meant to easily create custom icons to be used in a home automation setup.

<p align="center">
  The Paint web interface
</p>

To keep thing simple, the system works with 16 preset colors based on the original 4-bit palette of the 1987 Macintosh II:

<table style="border: none;">
<tbody><tr>
  <td style="color:black; background:#fff;">0 — white
  </td>
  <td style="color:black; background:#fbf305;">1 — yellow
  </td>
  <td style="color:black; background:#ff6403;">2 — orange
  </td>
  <td style="background:#dd0907;">3 — red
  </td>
  <td style="color:white; background:#f20884;">4 — magenta
  </td>
  <td style="background:#4700a5;">5 — purple
  </td>
  <td style="background:#0000d3;">6 — blue
  </td>
  <td style="color:black; background:#02abea;">7 — cyan
  </td>
</tr>
<tr>
  <td style="color:white; background:#1fb714;">8 — green
  </td>
  <td style="color:white; background:#006412;">9 — dark green
  </td>
  <td style="color:white; background:#562c05;">a — brown
  </td>
  <td style="background:#90713a;">b — tan
  </td>
  <td style="color:black;background: silver;">c — light grey
  </td>
  <td style="background: grey;">d — medium grey
  </td>
  <td style="background:#404040;">e — dark grey
  </td>
  <td style="color:white; background:#000;">f — black
  </td>
</tr>
</tbody></table>

Source: [Wikipedia](https://en.wikipedia.org/wiki/List_of_software_palettes)

Other buttons:

- The ⭐ (star) is an additional 17th color that matches whatever color is currently used to display the time in normal operation; you can therefore customize it.

- The 🗑️ (trashcan) clears the screen (turns all LEDs black).

- The 🕑 (clock) transitions the clock back in normal time display mode. Rember to use this when you're done painting or the clock will remain in paint mode indefinitely (or until reboot).

### Payload format

At the bottom of the page, a text version of the image payload is displayed, so it can be copied and used in direct [MQTT](#mqtt-client) or [HTTP GET](#api-1) calls, for example to be used in home automation scenarios.

The payload is a string of 110 characters, one for each LED/pixel in the 11x10 matrix, starting from the top left corner. Allowed values are:

- `0` to `f` representing the hexadecimal index of one of the 16 colors from the preset palette,
- `x` representing whatever color is currently selected for displaying the time.

## Text scroller

__Note:__ This is an experimental feature. Parameters might change.

This feature scrolls a text on the display (only ASCII characters are supported) then goes back to displaying the time ([demo video](https://www.youtube.com/watch?v=WIv3Row_7ro)). It accepts a string of any length between 1 and 200 characters.

It can be used from the [API](#api-1) and from [MQTT](#mqtt-client). Both options support the same parameters.

#### Parameters

The feature supports a few optional parameters:

- `color` should match a character code from the [Paint](#paint) palette, i.e. `0` to `f` or `x`, see [payload format](#payload-format). Defaults to the current color (`x`).
- `delay` define the time in milliseconds between each frame. The lower the number, the faster the scroll speed. Defaults to 200.
- `rtl` if set to `1`, scroll from right to left. Defaults to left to right.

#### API

When the API endpoint is enabled in the [settings](#api), you can hit `http://<clock IP>/api/text/set/<custom text>` and pass the optional settings as query parameters. For example to scroll the message `Hello from API :)` in red color, scrolling backwards with 100ms delay, you'd do:

```
http://<clock IP>/api/text/set/Hello%20from%20API%20%3A)?color=3&delay=100&rtl=1
```

Note: the API endpoint can handle URI-encoded characters.

#### MQTT topic

The MQTT command topic is `wordclock/light/text/set` and its paylod is expected to be a JSON string containing the `text` value to scroll alongside any supported optional parameters. For example:

```json
{"text":"Hello from MQTT :)","color":"3","delay":100,"rtl":1}
```

## Credits

Parts of this page are inspired from the [template manual provided by IotWebConf](https://github.com/prampec/IotWebConf/blob/master/doc/UsersManual.md).

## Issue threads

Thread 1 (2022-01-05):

Can't compile the code.

rilindnuka, 2022-01-05:
Great project, i like it a lot
I can't get it to compile though... I get the following when i try to compile the provided code.
I am probably missing something and not seeing it.

`In file included from /Users/rilindnuka/Documents/personal/wordclock/software/wordclock/wordclock.ino:9:0:
/Users/rilindnuka/Documents/personal/wordclock/software/wordclock/src/Iot.h:64:3: error: 'IotWebConfParameter' does not name a type
   IotWebConfParameter ntp_enabled_param_;
   ^
/Users/rilindnuka/Documents/personal/wordclock/software/wordclock/src/Iot.h:69:3: error: 'IotWebConfParameter' does not name a type
   IotWebConfParameter timezone_param_;
   ^
/Users/rilindnuka/Documents/personal/wordclock/software/wordclock/src/Iot.h:74:3: error: 'IotWebConfParameter' does not name a type
   IotWebConfParameter manual_date_param_;
   ^
/Users/rilindnuka/Documents/personal/wordclock/software/wordclock/src/Iot.h:79:3: error: 'IotWebConfParameter' does not name a type
   IotWebConfParameter manual_time_param_;
   ^
/Users/rilindnuka/Documents/personal/wordclock/software/wordclock/src/Iot.h:84:3: error: 'IotWebConfParameter' does not name a type
   IotWebConfParameter show_ampm_param_;
   ^
/Users/rilindnuka/Documents/personal/wordclock/software/wordclock/src/Iot.h:89:3: error: 'IotWebConfParameter' does not name a type
   IotWebConfParameter ldr_sensitivity_param_;
   ^
/Users/rilindnuka/Documents/personal/wordclock/software/wordclock/src/Iot.h:94:3: error: 'IotWebConfParameter' does not name a type
   IotWebConfParameter color_param_;
   ^
/Users/rilindnuka/Documents/personal/wordclock/software/wordclock/src/Iot.h:99:3: error: 'IotWebConfSeparator' does not name a type
   IotWebConfSeparator time_separator_;
   ^
/Users/rilindnuka/Documents/personal/wordclock/software/wordclock/src/Iot.h:100:3: error: 'IotWebConfSeparator' does not name a type
   IotWebConfSeparator display_separator_;
   ^
exit status 1
Error compiling for board ESP32 Dev Module.`

kvlavieren, 2022-01-12:
I have the same issue.

t0mg, 2022-01-12:
Hello and thanks for your interest :)

IotWebConf had a major (breaking) update since I published this, you might need to use an older version (check the packages file). I need to rewrite the code to use the latest version but unfortunately I lack the time to do so at the moment :/

Let me know it that helps!

t0mg, 2024-01-07:
I have now tagged a 1.0 release and attached a prebuilt binary https://github.com/t0mg/wordclock/releases

Some updates are coming to this project, including hopefully upgrading the iotwebconf library to a later release.

t0mg, 2024-01-09:
iotwebconf is now updated to latest, closing this issue now :)

Closed 2024-01-09.

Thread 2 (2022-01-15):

Only 3 Leds light up (5, 6 and 7 in the chain)

gordonBimig, 2022-01-15:
Hi,

I flashed the code to a Wemos D1 mini ESP32. I was able to connect to the Webserver and integrate it into my local WIFI Network. However, the only thing that changes is the LED color (if changed over the Webserver page). All other changes (show am/pm, changing the time manually or retrieving it over a time server) remain without any effect. Always the same 3 LEDs light up.

What could be the issue here?

t0mg, 2022-01-15:
Hi Gordon,

wow that's pretty weird, never happened to me. Maybe an addressing issue ? I'd first check the wiring, then use a basic test sketch to turn all the LEDs on one by one (not all together unless you have a separate power upply and are not using USB power) just to make sure the entire LED chain is working. If that works, then in the wordclock code I'd turn on serial debugging (#define DEBUG 1) and put some DLOGLN() to see what's running, especially in the Display.cpp and ClockFace.cpp files.

gordonBimig, 2022-01-16:
Hi t0mg,

thanks for the quick response. Don't know what the issue was, maybe the incorrect face/matrix configuration?
I have a 10x10 matrix layout with a diffrent word/letter arrangement then in your english face config. After I adjusted  some of the definitions in clockface.cpp an reuploaded the sketch (via Arduino IDE) and it seemed to work better, however the words/leds didn't match for a obvious reason. Since you code is pretty clean 👍 :-) and well documented I was able to translate the definitions to my environment, woohoo.

However, I'm still having some issues/questions:

I eanbled logging and am getting this result:

```
Logging started.
DCHECK Line 22: (result) RTC didn't start
Config size: 261
Loaded config 'iwcThingName'= 'WordClock'
Loaded config 'iwcApPassword'= <hidden>
Loaded config 'iwcWifiSsid'= '***'
Loaded config 'iwcWifiPassword'= <hidden>
Loaded config 'iwcApTimeout'= '30'
Loaded config 'show_ampm'= '0'
Loaded config 'ldr_sensitivity'= '5'
Loaded config 'color'= '#0000ff'
Loaded config 'ntp_enabled'= '0'
Loaded config 'timezone'= '356'
Loaded config 'time'= '05:53:55'
Updating color
update state
Invalid minute 165
Time: 165:165
State changing from: 0 to 2
Setting up AP: WordClock
Use password: <hidden>
AP IP address: 192.168.4.1
State changed from: 0 to 2
State changing from: 2 to 3
Connecting to [***] (password is hidden)
State changed from: 2 to 3
WiFi connected
IP address: 192.168.44.41
State changing from: 3 to 4
Accepting connection
Wifi connected.
NTP time setting is disabled.
State changed from: 3 to 4
```

Despite diabling the ntp time feature and setting the time to eg. 05:53:55 the clock is showing "it is ten" (which is the correct time, but I guess it should display the manual time? (which seems to have been stored correctly)
I also notice that the display doesn't seem to update the, despite outputing "Updating display" in the serial monitor.

Then I changed the time to NTP again and get this output, but the display (it is ten) stays the same. Any clue what I'm doing wrong?

```
Updating configuration
Value of arg 'iwcThingName' is:WordClock
iwcThingName='WordClockWordClock'
Value of arg 'iwcApPassword' is:
iwcApPassword was not changed
Value of arg 'iwcWifiSsid' is:***
iwcWifiSsid='***'
Value of arg 'iwcWifiPassword' is:
iwcWifiPassword was not changed
Value of arg 'show_ampm' is:0
show_ampm='00'
Value of arg 'ldr_sensitivity' is:5
ldr_sensitivity='55'
Value of arg 'color' is:#0000ff
color='#0000ff#0000ff'
Value of arg 'ntp_enabled' is:1
ntp_enabled='11'
Value of arg 'timezone' is:356
timezone='356356'
Value of arg 'time' is:
time=''
Saving config 'iwcThingName'= 'WordClock'
Saving config 'iwcApPassword'= <hidden>Saving config 'iwcWifiSsid'= '***'
Saving config 'iwcWifiPassword'= <hidden>Saving config 'iwcApTimeout'= '30'
Saving config 'show_ampm'= '0'
Saving config 'ldr_sensitivity'= '5'
Saving config 'color'= '#0000ff'
Saving config 'ntp_enabled'= '1'
Saving config 'timezone'= '356'
Saving config 'time'= ''
Configuration was updated.
Updating color
RTC set to:Sunday, January 16 2022 09:38:48
Timezone:Europe/Berlin
```

I noticed that the output of iwcWifiSsid return 2 times the actual WiFi SSID. Not sure where the output comes from, since I couldn't find this string in your code.

And this happens, when pushing the reset buttons of the wemos d1 mini esp32:

```
ets Jun  8 2016 00:22:57

rst:0xc (SW_CPU_RESET),boot:0x13 (SPI_FAST_FLASH_BOOT)
configsip: 0, SPIWP:0xee
clk_drv:0x00,q_drv:0x00,d_drv:0x00,cs0_drv:0x00,hd_drv:0x00,wp_drv:0x00
mode:DIO, clock div:1
load:0x3fff0018,len:4
load:0x3fff001c,len:1044
load:0x40078000,len:10124
load:0x40080400,len:5856
entry 0x400806a8
Logging started.
DCHECK Line 22: (result) RTC didn't start
Config size: 261
Loaded config 'iwcThingName'= 'WordClock'
Loaded config 'iwcApPassword'= <hidden>
Loaded config 'iwcWifiSsid'= '***'
Loaded config 'iwcWifiPassword'= <hidden>
Loaded config 'iwcApTimeout'= '30'
Loaded config 'show_ampm'= '0'
Loaded config 'ldr_sensitivity'= '5'
Loaded config 'color'= '#0000ff'
Loaded config 'ntp_enabled'= '1'
Loaded config 'timezone'= '356'
Loaded config 'time'= ''
Updating color
Wifi not connected, cannot set time from NTP.
update state
Invalid minute 165
Time: 165:165
State changing from: 0 to 2
Setting up AP: WordClock
Use password: <hidden>
AP IP address: 192.168.4.1
State changed from: 0 to 2
State changing from: 2 to 3
Connecting to [***] (password is hidden)
State changed from: 2 to 3
WiFi connected
IP address: 192.168.44.41
State changing from: 3 to 4
Accepting connection
Wifi connected.
RTC set to:Sunday, January 16 2022 09:45:23
Timezone:Europe/Berlin
State changed from: 3 to 4
```

The output Invalid minute/invalid hour, refers to the timeserver not beeing set since the wifi is not connected I guess?

However, lot's of questions and not understood things in my head. Would appreciate your support very much :-)

gordonBimig, 2022-01-16:
Nevermind?

I thought die RTC module is optional, since the esp32 has wifi and time can be otained via wifi?

I just soldered a RTC module to the esp32 and voila, the clocks works now. I'm really impressed by your software. Very well done :-)

https://www.directupload.net/file/d/6430/bjy5mj5n_jpg.htm

gordonBimig, 2022-01-16:
Well, there is still one little little issue left I could need some assistance.

One minute, before the next time display occurs, the third pixel/letter  "u" (between it and is) lights up. Cannot figure out why that is. No word is defined at this coordinate or before with a length larger 2:

Do you have a clue why?

Here is my clockface definition:
```
//     0123456789
// 09: ITUISJAXMY
// 08: TWENTYHALF
// 07: HAPPYHFIVE
// 06: TENQUARTER
// 05: TOPASTBDAY
// 04: ONEFOURTWO
// 03: FIVESIXTEN
// 02: THREESEVEN
// 01: TWELVEIGHT
// 00: NINELEVENJ

// All the segments of words on the board. The first too numbers are the
// coordinate of the first letter of the word, the last is the length. A word
// must always be on one row.

#define EN_S_IT 0, 9, 2
#define EN_S_IS 3, 9, 2

#define EN_H_ONE 0, 4, 3
#define EN_H_TWO 7, 4, 3
#define EN_H_THREE 0, 2, 5
#define EN_H_FOUR 3, 4, 4
#define EN_H_FIVE 6, 7, 4
#define EN_H_SIX 4, 3, 3
#define EN_H_SEVEN 5, 2, 5
#define EN_H_EIGHT 5, 1, 5
#define EN_H_NINE 0, 0, 4
#define EN_H_TEN 7, 3, 3
#define EN_H_ELEVEN 3, 0, 6
#define EN_H_TWELVE 0, 1, 6

#define EN_H_AM 6, 9, 2
#define EN_H_PM 7, 9, 2

#define EN_M_A 6, 9, 1
#define EN_M_PAST 2, 5, 4
#define EN_M_TO 0, 5, 2

#define EN_M_TEN 0, 6, 3
#define EN_M_QUARTER 3, 6, 7
#define EN_M_TWENTY 0, 8, 6
#define EN_M_TWENTYFIVE 0, 7, 10
#define EN_M_FIVE 6, 7, 4
#define EN_M_HALF 6, 8, 4
#define EN_M_QUART 3, 6, 7
#define EN_M_QUARTS 3, 6, 7

#define EN_M_OCLOCK 0, 9, 1
```

Here is a picture showcasing the problem:

https://s20.directupload.net/images/220116/vhscwe6o.jpg

t0mg, 2022-01-16:
Yes I was going to write that it looks like you have no RTC module. This clock was designed with the RTC module in mind, setting the time via NTP was added later as a bonus. So yes in the code the RTC module is taken for granted. Even if you use NTP time, currently it gets the time once after you save the settings and then stores this in the RTC module. The idea is that you don't *need* wifi to use the clock once it has been setup.

But you can certainly change that and make it so that the clock checks for NTP every time it powers up, and remove the RTC module :)

Thanks for the picture, looks great 👍
Congratulations on building your new clock! 🙂

t0mg, 2022-01-16:
Re. the letter turning one 1 minute before the time change its probably because the led strip normally starts with 4 LEDs (one in each corner) that each indicate a minute, so eg when it is 10:13, the clock reads "it is ten past ten" and three of the 4 corner LEDs light up to indicate that you need to add +3 to the text.

Now it looks like you don't have corner LEDs? The first LEDs in your chain are not corner leds so it's probably some code that you need to comment out to remove this behavior.

gordonBimig, 2022-01-16:
Correct, no corner LEDs, that's why i thought this code change would fit my enviroment :-)

// The number of LEDs connected before the start of the matrix.
#define NEOPIXEL_SIGNALS 0

The default was 4, assuming for the 4 corner LEDs?

So does that mean the value "0" in this parameter doesn not work with the current version of the software?

gordonBimig, 2022-01-16:
Solved it by removing "switch (leftover)" in Clockface.cpp :-)

Closed 2022-01-16.

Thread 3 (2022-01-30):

cannot connect

winner69, 2022-01-30:
Hi Tom, I finished upload  your code to ESP32,
my mobile cannot find AP name "wordclock"

t0mg, 2024-01-07:
Sorry about this @winner69. There could be many reasons to that symptom. I know it's been a while but if you're still interested, could you try building the project with debug enabled to see if anything useful comes up on the serial interface ? Please feel free to reopen the issue if you have more information. Thanks!

Closed 2024-01-07.

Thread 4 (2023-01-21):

This code is for a clock that uses an Adafruit TLC5947 LED driver, a real-time clock (RTC), a TMRpcm audio library, and an SD card. It sets the current time on the clock using the RTC and displays the time on the LEDs using the TLC5947. It also plays audio files from the SD card at specified times and has alarm functionality. The code uses a number of global variables to keep track of the current time and other settings, and it has a number of functions including setup() and displayupdate(). It should be noted that the code is incomplete, it's missing a lot of the functions and some of the lines are not complete.

ShoaibAliWains, 2023-01-21:

ShoaibAliWains, 2023-01-21:
This code is for a clock that uses an Adafruit TLC5947 LED driver, a real-time clock (RTC), a TMRpcm audio library, and an SD card. It sets the current time on the clock using the RTC and displays the time on the LEDs using the TLC5947. It also plays audio files from the SD card at specified times and has alarm functionality. The code uses a number of global variables to keep track of the current time and other settings, and it has a number of functions including setup() and displayupdate().
It should be noted that the code is incomplete, it's missing a lot of the functions and some of the lines are not complete.

t0mg, 2023-02-13:
Sounds like a chat bot?

Closed 2023-02-13.

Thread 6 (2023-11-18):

esp32 constantly restarts (SW_CPU_RESET)

Gehilfe, 2023-11-18:
Hello,
I can't get the code to work on an esp32-Wroomer-32. There is no error message when compiling, the transfer also works without problems. However, I always get the following message via the serial monitor:

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

The problem occurs regardless of whether I use Platform.io or the Arduino IDE. I have also tried different versions of the libraries. I am currently using the following libraries under Platform.io:
	prampec/IotWebConf@2.3.1
	adafruit/RTClib
	makuna/NeoPixelBus@2.5.5

To rule out a possible defect in the microcontroller, I have now used 3 different esp32. The same error pattern occurs with all three.

I would be pleased if you could give me a tip. I have already searched the net desperately for possible solutions, but have found nothing.

Gehilfe, 2023-11-18:
Short update: output in Verbose Mode

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

tjfsteele, 2023-11-29:
I think I have fixed this. See the next issue.

Gehilfe, 2023-11-29:
Thank you! I´ll try it tomorrow :)

Gehilfe, 2023-12-06:
Sorry, I haven't had time to test if it works with the changed code. But tomorrow I should finally get around to it. I would then close the issue myself.

t0mg, 2024-01-07:
Hello and happy new year. I think it should be resolved now. Can you please confirm ?

Gehilfe, 2024-01-07:
I apologize for any inconvenience. I still haven't managed to try the workaround. I'll just close the thread and get back to you if it didn't work. Thanks for the support and happy new year as well 😀

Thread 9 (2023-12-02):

Crashes on ESP32C3

tjfsteele, 2023-12-02:
Timer.cpp line 32 tries to create timer 3 but the ESP32C3 only has two.

Suggest changing the line to

`    timer_ = timerBegin(1, 8000, 1); // div 80
`

t0mg, 2023-12-06:
Would you mind sending a PR?

Note: I plan on updating this project with the new version of IOTWebConf but this got delayed by external factors (I broke my own clock). Any contribution towards maintaining this project is most welcome :)

Thanks!

tjfsteele, 2023-12-07:
I've submitted a PR. Thank you for accepting the previous one.

tjfsteele, 2023-12-10:
> Note: I plan on updating this project with the new version of IOTWebConf but this got delayed by external factors (I broke my own clock). Any contribution towards maintaining this project is most welcome :)

May be able to help - email github@tjfs.com

t0mg, 2023-12-10:
Thanks for the PR. Happy to discuss if you're willing to help further! On my side I don't think I'll be able to work on this before end of year.

tjfsteele, 2023-12-11:
Might be helpful if we could chat on email as opposed to github?

Thanks

Tim

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

tjfsteele, 2023-12-19:
> Happy to discuss if you're willing to help further!

Hope to hear from you soon.

Tim

Closed 2023-12-10.

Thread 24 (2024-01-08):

Network box

IlGiurgi, 2024-01-08:
Is it possible  to hide the network box or to collapse it if the network is already set up? or at least place it at the bottom.

t0mg, 2024-01-09:
Yes, good idea. I'll look into it.

t0mg, 2024-01-10:
Thanks ! your Italian clock face was just added to the repository with PR #27

Regarding updates not working, there was a timer bug that was just fixed yesterday that could have caused this, but if you are still able to reproduce it would be helpful to see if there's any info on the serial console.

As for AMPM it's the same with French actually (unused too), I need to think of a simple way to toggle that.

IlGiurgi, 2024-01-11:
Can I reach out to you somehow? I have issues with the new code. If you can, text me at @ilgiurgi on telegram.

t0mg, 2024-01-11:
Sorry I'm not in telegram. Feel free to file as many issues as necessary here! It might help others.

IlGiurgi, 2024-01-11:
For some reason I messed up something maybe with the cables or something but the ESP keeps rebooting with the code, I tried uploading a code to see if each component works well and they do, so I can't figure out what's the reason of the reboots.. That's the error, I always used same usb cables ecc so it could be the board maybe?
12:51:36.869 ->
12:51:36.869 -> Brownout detector was triggered
12:51:36.869 ->
12:51:36.869 -> ets Jul 29 2019 12:21:46
12:51:36.869 ->
12:51:36.869 -> rst:0xc (SW_CPU_RESET),boot:0x13 (SPI_FAST_FLASH_BOOT)
12:51:36.869 -> configsip: 0, SPIWP:0xee
12:51:36.869 -> clk_drv:0x00,q_drv:0x00,d_drv:0x00,cs0_drv:0x00,hd_drv:0x00,wp_drv:0x00
12:51:36.869 -> mode:DIO, clock div:1
12:51:36.869 -> load:0x3fff0030,len:1344
12:51:36.869 -> load:0x40078000,len:13964
12:51:36.869 -> load:0x40080400,len:3600
12:51:36.869 -> entry 0x400805f0

t0mg, 2024-01-11:
Uh oh `Brownout detector was triggered` ?

Is the power supply too weak?

t0mg, 2024-01-11:
Ok thanks for the heads up I will also do some testing

t0mg, 2024-01-12:
As of 1d2bcd9 there is now a language selector (including italian) and we hide the am/pm if unused. We also move the network section to the bottom after initial setup.

I've tested the firmware on my clock and it works without issue, so I'll close this ticket (which was about the network section of the web UI) but feel free to open another if your issues persist!

Closed 2024-01-12.

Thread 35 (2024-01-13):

Home automation integration

K-Brix, 2024-01-13:
This is a feature request .

Is there a possibility to add either a REST api or a Mqtt client to your project.
I would like to be able to change at least the color, the brightness from home assistant.
Case use would be to switch off the leds when no one is in the room or dim when the tv is on etc. Also the color could be changed for instance when someone is ringing or the temperature is under 0…
I checked the IotWebConf project and it seems that it can handle these features.

https://github.com/prampec/IotWebConf/blob/master/examples/IotWebConf06MqttApp/IotWebConf06MqttApp.ino

Is it something you would consider?

t0mg, 2024-01-13:
Yes mqtt is planned, stay tuned :)

K-Brix, 2024-01-14:
> Yes mqtt is planned, stay tuned :)

Nice. Can’t wait. Very cool to see this repo getting some features and polishing.

t0mg, 2024-01-15:
there's now a minimalist implementation where you can configure mqtt from the web ui and then just publish to "color/set" with a hexa color value. it's still wip but feedback would be welcome

t0mg, 2024-01-15:
@K-Brix "color/set" works nicely from my testing.

Since you have concrete plans for it, do you have any suggestions of features to implement for the mqtt client?

Is there a point in publishing a state topic? What kind of info?

Anything relevant to listen to beyond color setting ? Brightness is a bit annoying because it would conflict with the LDR sensor. Setting a darker color from HA would not conflict with that and achieve the same result.

Should the color set via mqtt be saved to eeprom like the web UI does, or should a reboot restore last saved web UI value? (I'm leaning towards not persisting it).

Should we prefix the channel with the device name in case there are multiple ? Or make it configurable in the web UI maybe ?

K-Brix, 2024-01-16:
I haven’t had the time to test it yet cause you’re coding too fast.
Regarding what feature to expose to Mqtt:
I would like it to be automatically set up as a light in HA. This can be achieved by following these guidelines, either via Matt topics or via a single json payload (https://www.home-assistant.io/integrations/light.mqtt/)
For my use case, I would especially like to be able to turn off the ws leds altogether when no one is at home or at night, or by using a presence sensor.
Of course you can expose all the config in mqtt (langage, am/pm, …) and other informations like uptime, wifi strength, ambiant luminosity (could be used by other devices)
I think it’s OK to revert to the last saved color on reboot. But could be a user defined setting
The Chanel should be clearly identified either with the device name or a random sequence (wordclock_AEF5). Better yet if it’s user configurable but with a default to a unique id.
Thanks for your work.

K-Brix, 2024-01-17:
Ok, I compiled yesterday's code using plateformio (first time I tried it) and enabling loging to serial.
I tested it on a breadboard with no led plugged so I can confirm that this is working only from the logs feedback.

I can connect to my mqtt server with no trouble but wordclock doesn't publish any topic.
I was able to publish to color/set and got confirmation from the esp32 serial console:
```
Incoming: color/set - #f242f5
Updating color
Brightness has changed, updating
Updating display
```
However, the color change is not reflected in the webui wich still display the eeprom value:
```
|-- [display_group]
|   |-- 'boot_animation_enabled' with value: '1'
|   |-- 'clockface_language' with value: '2'
|   |-- 'show_ampm' with value: '0'
|   |-- 'ldr_sensitivity' with value: '0'
|   \-- 'color' with value: '#4be12d'
```

K-Brix, 2024-01-17:
Compiled again with last commit [f21b039](https://github.com/t0mg/wordclock/commit/f21b03952980a127c9f21456cdb5b59e421a434e)
I can now succesfully subscribe to wordclock/status/ldr and publish to wordclock/color/set

K-Brix, 2024-01-17:
Yes the topics names make sense as is. If you're open to suggestion, I'd propose
```
[clockname]/sensor/ldr -> current ldr reading
[clockname]/light/color -> current color
[clockname]/light/color/set -> publish hex color
[clockname]/light/switch -> on/off state of the light
[clockname]/light/switch/set (don't know if it's possible or if the color should be set to #000000 instead)
And maybe some user settings (/set)
[clockname]/config/language
[clockname]/config/ntp
[clockname]/config/timezone
[clockname]/config/ldrsensitivity
```
... the more the better :)

Regarding the ldr value update frequency, I'd say once every 15 seconds or so should be enough.
It would be confusing to add a webui config for such a niche feature. Maybe the update frequency could be in a #define somewhere in the code so that a user with specific needs could modify it before compiling

Thanks again

DaveDavenport, 2024-01-17:
Is it better to only publish on change, but with persistence flag set?

t0mg, 2024-01-17:
What is a persistence flag? Another option could be to request some info and the clock could publish when it gets a request

K-Brix, 2024-01-17:
That is called a retain flag. Should be implemented in the mqtt library cause it’s used a lot in the protocol. Tells the server to retain the value until it’s changed.
I would agree it’s best practice to publish on change but the ldr reading must change quite often.

t0mg, 2024-01-18:
Ok I see, in that case we should not publish the raw ldr measure as we were doing here. But surely this should work nicely for other types of information like current color.

t0mg, 2024-01-18:
Actually I'll keep it simple for now and just publish every 15s. K-Brix is right, changes happen more often than that. I can still set the retain flag. Same with color and all the rest actually.

t0mg, 2024-01-19:
Ok I followed your recommendation. As of commit 281a693 you have

- [clockname]/sensor/ldr -> current ldr reading
- [clockname]/light/color -> current color (r,g,b)
- [clockname]/light/color/set -> publish r,g,b color (**not hex** as it's not what HA is sending by default)
- [clockname]/light/switch -> "ON"/"OFF" state of the light
- [clockname]/light/switch/set -> send "ON"/"OFF" to toggle. Color is restored on "ON".

Sensor now publishes every 15s.
Note: I put every publish in "retain" I don't know if that's the way.

Here's an example configuration that works for me in HA:
```yaml
mqtt:
  - light:
      name: "Wordclock"
      state_topic: "wordclock/light/switch"
      command_topic: "wordclock/light/switch/set"
      rgb_state_topic: "wordclock/light/color"
      rgb_command_topic: "wordclock/light/color/set"
      payload_off: "OFF"
      payload_on: "ON"
      qos: 0
      optimistic: false
  - sensor:
      name: "Wordclock light sensor"
      state_topic: "wordclock/sensor/ldr"
```

If we are happy with this I'll document the MQTT feature.

K-Brix, 2024-01-19:
Ok sounds perfect to me. That's exactly what I needed and I will be testing it this weekend.
Just a question. The LDR reading on the ADC pin is in volt, is it?
there's a specific sensor type in esphome for this but I'm not sure I understand the point of it https://esphome.io/components/sensor/resistance

t0mg, 2024-01-19:
Added an availability topic ("offline"/"online") in 7648734 so HA can mark the clock as unavailable when it's disconnected instead of retaining the last known state.

```
mqtt:
  - light:
      name: "Wordclock"
      availability_topic: "wordclock/availability"
      state_topic: "wordclock/light/switch"
      command_topic: "wordclock/light/switch/set"
      rgb_state_topic: "wordclock/light/color"
      rgb_command_topic: "wordclock/light/color/set"
      qos: 0
      optimistic: false
  - sensor:
      name: "Light sensor"
      state_topic: "wordclock/sensor/ldr"
``

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

K-Brix, 2024-01-20:
Ok @t0mg I compiled and tested the most recent source code and I can confirm the mqtt implementation is working as expected, including home assistant mqtt light and sensor integration. should'nt be difficult to use it in homekit as well through HA. Same for Jeedom or other home automation system. Very happy with the whole thing. I have one clock in my office, but I'm considering building another one for my home (maybe 60x60 or 90x90 cm, your svg's should scale nicely and a whole lot more room for the electronics).

t0mg, 2024-01-20:
Thank you for your feedback! Lovely to hear that, all of it. Would love see that giant wordclock it you ever build it :)

Closing the ticket!

t0mg, 2024-02-25:
@K-Brix just a heads up that I've just added the ability to display custom content on the led matrix - as home assistant user I thought that might be useful to show icons in some automations.

Details : https://github.com/t0mg/wordclock/blob/main/software/UsersManual.md#paint

K-Brix, 2024-02-25:
Nice touch. I may have some ideas like special icons on family birthdays, an icon warning when the house uses too much electricity and the price is high....

t0mg, 2024-03-01:
Thanks for the feedback, let me know if it works for you!

Closed 2024-01-20.

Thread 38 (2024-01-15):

Updating color sometimes fail ?

t0mg, 2024-01-15:
Sometimes (in my experience, only when a full brightness color is selected), a color change isn't taken into account until reboot, or, which is weird, if we first switch to a dimmer color or to full black, which seems to consistently "unblock" the color. Reproduced on the original wroom esp32 and esp32c3.

Seems related to the brightness controller, as I could not reproduce the issue when auto brigthness is set to 0 (disabled).

t0mg, 2024-01-15:
fixed in ee578f4

Closed 2024-01-15.

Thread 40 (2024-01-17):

Make default timezone depend on language selected (enhancement request)

tjfsteele, 2024-01-17:
If the user has not selected a timezone, instead of choosing Paris make the default timezone depend on language, e.g. English=London

t0mg, 2024-01-17:
Hmm I see how it would make more sense than Paris but on the other hand there are many other English speaking countries :)

K-Brix, 2024-01-19:
Default to utc would make the most sense but we’re talking about a clock that you need to build with a laser cnc, solder the electronic and compile the software: the average builder should be able to change the time zone without much trouble.

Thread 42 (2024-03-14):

Display ip address at startup with led matrix

LePtitNicolas, 2024-03-14:
Hi,

I am in the process of making a clock. I took your version with the "paint" functionality and the mqtt options because I think it opens up interesting perspectives!

I was thinking about a function to display scrolling text using the LEDs as a matrix.
It would thus be possible to display the IP address of the clock at startup, for example. It would be really very practical to know if it is in AP mode or if it is connected to the local network and in the latter case, to have the IP address to connect to it without having to plug in a USB cable to know it with the serial monitor or having to look for it on the box.
The function could also be used to display a scrolling message sent via an mqtt request. We could imagine programming messages on Home Assistant for events (happy birthday, merry Christmas, etc.)

But I admit that I am not comfortable enough with programming to implement this development...

DaveDavenport, 2024-03-14:
Not sure if we can easily display every ip address on each faceplate.

In  AP mode your browser should automatically redirect to the wordclock webpage.

Once connected to your wifi, I think the clock should be reachable via the wordclock.local hostname (with default settings).

t0mg, 2024-03-17:
Local domain doesn't work with all routers, but it's definitely worth trying :) On the other hand, routers/boxes all provide a way to list connected devices so you should not need to use serial to discover the IP anyway.

A generic scrolling text / ticker feature over mqtt is a logical next step after paint mode. I just lack the time to work on that 😅

After that, showing the IP after connection would be doable. Generally speaking having some info during boot could be cool. It is rather niche though, as normally you'd only need that once. A generic text ticker however could be nice for home automation purposes.

LePtitNicolas, 2024-03-20:
Thanks for taking the time to respond !

Indeed, the display of the IP address should only be used at startup, which should be rare, however, the generic scrolling text / ticker feature over mqtt will be a real plus :-p

t0mg, 2024-10-01:
Generic text scroller feature is now available :)
https://github.com/t0mg/wordclock/blob/main/software/UsersManual.md#text-scroller

t0mg, 2024-10-13:
Feature added in a83c5e8

Closed 2024-10-13.

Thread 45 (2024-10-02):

Impossible to change Time

antoblasco, 2024-10-02:
I Tom,

I’m trying to change the time manually but doesn’t work. The HMI said "configuration saved", but is not true. Could you help me please?

t0mg, 2024-10-02:
Thanks @antoblasco. I can reproduce the issue. Looks like we broke manual time setting at some point (I'm always using NTP so I hadn't noticed before). Will have a look.

antoblasco, 2024-10-03:
No because at the moment I don’t need it

antoblasco, 2024-10-03:
I see that you close the issue without any new release, why @t0mg ?

at the moment I’m not able to change the code, I haven’t too much programming skill 😆🙈 for me will be better a new SW release via OTA

DaveDavenport, 2024-10-03:
It is closed because its fixed in https://github.com/t0mg/wordclock/commit/b31e9b50376087dfdd1c8171b805425b68cc3940 .  This will be part of a next release.
A release is normally more then a single issue and consists of a collection of closed issues and new features.

antoblasco, 2024-10-03:
Ok ok I didn’t know. No problem, I can wait. Thank you a lot really for your support. I’m new on GitHub and I don’t know all’ the procedure, sorry.

t0mg, 2024-10-03:
I was about to publish a new release anyway:)

I'm not sure this issue is really closed though if you didn't have MQTT enabled. But in that case I am not able to reproduce your problem on my wordclocks

t0mg, 2024-10-03:
@antoblasco new release is available with this fix. You can update over wifi via the firmware update link in the config page using the provided ota.bin file, or flash via USB with the other bin file. But if you don't use mqtt your problem might be something else. Let us know.

Closed 2024-10-02.

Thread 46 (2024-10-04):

Animation transition time too slow

antoblasco, 2024-10-04:
Hi all,

after a couple of days of always ON working, I’ve notice that the animation transition time become very slow. You need to wait sometimes also 30/40s to see the leds reaching the brightness from 0 to the defined level.

What is the problem for you? Not enough memory? Not enough CPU clock?

Is it possible to add in the homepage a slider to activate and deactivate the transition between each minute or word please?

thanks

antoblasco, 2024-10-04:
No MQTT enable, no new release uploaded, network time ON

antoblasco, 2024-10-04:
Now with the Sun outside I see that with a lot of ambient light is more fast. So maybe became very slow with few ambient light

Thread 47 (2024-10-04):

Red color of startup animation doesn’t work properly

antoblasco, 2024-10-04:
Hi all,

After trying to resolve the issue 46 by unplug and plug the power a couple of time also waiting more than 5 minutes between the unplug and plug, I’ve noticed that the color red during the startup animation, doesn’t turn ON a lot of leds.

At the beginning was everythink ok.

The strip led is not broken, infact the white color is working properly on all LEDs.

This issue can be related to the 46 or you think that there is an other problem?

thanks

t0mg, 2024-10-04:
I've noticed it. Blocking operations at boot time prevent the animation from showing. Not a huge problem IMO but we could delay the boot animation to reduce this (which would make startup time longer).

antoblasco, 2024-10-04:
Hi @t0mg , I think that is not necessary to startup the clock fastly, it’s just a clock. So I think that we could try to use your solution to resolve this issue, because the startup animation is also helpfull to understand if there’s a damaged led 😄

I’m really happy to debug the SW and help all of you to reach the best release 💪🏻

Closed 2024-10-13.

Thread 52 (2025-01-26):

Clock not showing time

Thunfeld, 2025-01-26:
So, I've been trying for a couple of days to get the clock to work with some success, but apart from the main part, which is displaying the time, I'm having issues.

I have configured the clock in Dutch, and everything went well on that part. The Wi-Fi is connecting, the painting tool is working well (pixels line up), but the time is stuck displaying:

> "HET IS TIEN"

Sometimes it changes to:

> "HET IS TWAALF UUR"

but it’s not 12 o'clock anyway.

I have a feeling this might have something to do with the NTP server, which I have changed a couple of times without any luck. I even forwarded port (NTP) 123 to the IP address of the word clock, also with no success.

I am not using an RTC module. Could this be the issue?
So, hardware-wise, I only have an ESP-32 Dev module, nothing else.
I have accounted for this in Platform.io:

```
[env:esp32dev]
board = esp32dev
```

What am I missing here?
Thank you for taking the time to look into this.

Best regards,
Hunfeld

Thunfeld, 2025-01-27:
So i fixed it myself. It turns out i do need a RTC module ;)

Thunfeld, 2025-01-27:
So i fixed it myself. It turns out i do need a RTC module ;)

t0mg, 2025-01-30:
@DaveDavenport we should merge it back

DaveDavenport, 2025-01-30:
@t0mg  Can you assign this issue to me?

t0mg, 2025-01-30:
Gladly 😅

DaveDavenport, 2025-02-07:
@t0mg  can you reopen this one?

Thunfeld, 2025-02-07:
> [@t0mg](https://github.com/t0mg) can you reopen this one?
Oh im sorry did not know you wanted to work on it still.

DaveDavenport, 2025-02-07:
Yeah, its my intention to merge back the code I've added to run without external RTC and just use NTP and internal rtc.

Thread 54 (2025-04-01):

Cant see ldr value in Homeassistat

JayPi01, 2025-04-01:
Hi,

In my nodo Web UI I  enabled and configured the mqtt client connection and it works fine.
Then I configured  HomeAssistant as described in the manual:

mqtt:
  - light:
      name: "Wordclock"
      availability_topic: "wordclock/availability"
      state_topic: "wordclock/light/switch"
      command_topic: "wordclock/light/switch/set"
      rgb_state_topic: "wordclock/light/color"
      rgb_command_topic: "wordclock/light/color/set"
      qos: 0
      optimistic: false
  - sensor:
      name: "Light sensor"
      availability_topic: "wordclock/availability"
      state_topic: "wordclock/sensor/ldr"

In HomeAssistant I can see the 'wordclock/light' entity and I can set color and on/off.
But unfortunately the 'sensor' entity is not visible. Any ideas?

t0mg, 2025-04-06:
Hey, sorry I can't reproduce your issue. Did you figure it out?

JayPi01, 2025-04-07:
Kind of...
When I comment out the line 'state_topic: "wordclock/sensor/ldr"'' it works.

t0mg, 2025-04-07:
Thanks for letting us know. I don't understand what's going on though 😅

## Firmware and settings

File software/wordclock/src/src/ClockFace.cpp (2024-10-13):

#include "logging.h"

#include <NeoPixelBus.h> // Only need NeoTopology

#include "ClockFace.h"

#include "nodo.h" // Nodo stuff

// Number of LEDs on the whole strip.
#define NEOPIXEL_COUNT (NEOPIXEL_ROWS * NEOPIXEL_COLUMNS + NEOPIXEL_SIGNALS)

// static
int ClockFace::pixelCount()
{
  return NEOPIXEL_COUNT;
}

void ClockFace::clearDisplay(void)
{
  std::fill(_state.begin(), _state.end(), false);
  _hour = -1;
  _minute = -1;
}

ClockFace::ClockFace(LightSensorPosition position) : _hour(-1), _minute(-1), _second(-1),
                                                     _position(position), _state(NEOPIXEL_COUNT){};

void ClockFace::setLightSensorPosition(LightSensorPosition position)
{
  _position = position;
}

uint16_t ClockFace::map(int16_t x, int16_t y)
{
  switch (_position)
  {
  case LightSensorPosition::Top:
  {
    static NeoTopology<ColumnMajorAlternating90Layout> sensor_on_top(
        NEOPIXEL_COLUMNS, NEOPIXEL_ROWS);
#ifdef NODO
    int ind, inc;
    // do conversion from normal coordinates to Nodo coordinates
    ind = sensor_on_top.Map(x, y);
    if (ind < 11)
      inc = 1; // one pixel before first row
    else if (ind < 99)
      inc = 2; // two pixels before second row
    else
      inc = 3; // three pixels
    // mirror pixel grid
    ind = 11 * (ind / 11) + 10 - ind % 11;
    return ind + inc;
#else
    return sensor_on_top.Map(x, y) + NEOPIXEL_SIGNALS;
#endif
  }
  case LightSensorPosition::Bottom:
  {
    static NeoTopology<ColumnMajorAlternating270Layout> sensor_on_bottom(
        NEOPIXEL_COLUMNS, NEOPIXEL_ROWS);
    return sensor_on_bottom.Map(x, y) + NEOPIXEL_SIGNALS;
  }
  default:
    DCHECK(false, static_cast<int>(_position));
    return 0;
  }
}

uint16_t ClockFace::mapMinute(Corners corner)
{
  switch (_position)
  {
  case LightSensorPosition::Bottom:
    return (static_cast<uint16_t>(corner) + 2) % 4;
  case LightSensorPosition::Top:
#ifdef NODO
    switch (static_cast<uint16_t>(corner))
    {
    case 0:
      return 113;
    case 1:
      return 101;
    case 2:
      return 12;
    default:
      return 0;
    }
#else
    return static_cast<uint16_t>(corner);
#endif
  default:
    DCHECK(false, static_cast<int>(corner));
    return 0;
  }
}

// Lit a segment in updateState.
void ClockFace::updateSegment(int x, int y, int length)
{
  for (int i = x; i <= x + length - 1; i++)
    _state[map(i, y)] = true;
}

//
// Constants to match the ClockFace.
//
// Custom French face. Can show time with some less usual variations like
// MINUIT TROIS QUARTS or DEUX HEURES PILE. This also includes all the letters
// of the alphabets as well as !. Letters in lowercase below are not used
// by the clock.

// ILbESTjDEUX
// QUATRETROIS
// NEUFUNESEPT
// HUITSIXCINQ
// MIDIXMINUIT
// ONZEwHEURES
// MOINSyLEDIX
// ETTROISDEMI
// VINGT-CINQk
// QUARTSPILE!

// Alt version: same except last 3 lines
// ETbQUARTpmm
// VINGT-CINQu
// ETyDEMIEpam

// Comment out to not use alt version
#define FR_ALT

// All the segments of words on the board. The first too numbers are the
// coordinate of the first letter of the word, the last is the length. A word
// must always be on one row.
#define FR_S_IL 0, 0, 2
#define FR_S_EST 3, 0, 3

#define FR_H_UNE 4, 2, 3
#define FR_H_DEUX 7, 0, 4
#define FR_H_TROIS 6, 1, 5
#define FR_H_QUATRE 0, 1, 6
#define FR_H_CINQ 7, 3, 4
#define FR_H_SIX 4, 3, 3
#define FR_H_SEPT 7, 2, 4
#define FR_H_HUIT 0, 3, 4
#define FR_H_NEUF 0, 2, 4
#define FR_H_DIX 2, 4, 3
#define FR_H_ONZE 0, 5, 4

#define FR_H_HEURE 5, 5, 5
#define FR_H_HEURES 5, 5, 6

#define FR_H_MIDI 0, 4, 4
#define FR_H_MINUIT 5, 4, 6

#define FR_M_MOINS 0, 6, 5
#define FR_M_LE 6, 6, 2
#define FR_M_ET 0, 7, 2
// #define FR_M_TROIS 2, 7, 5 -- unused

#define FR_M_DIX 8, 6, 3
#define FR_M_VINGT 0, 8, 5
#define FR_M_VINGTCINQ 0, 8, 10
#define FR_M_CINQ 6, 8, 4
#ifdef FR_ALT
#define FR_M_ET2 0, 9, 2
#define FR_M_DEMI 3, 9, 5
#define FR_M_QUART 3, 7, 5
#else
#define FR_M_DEMI 7, 7, 4
#define FR_M_QUART 0, 9, 5
#endif
// #define FR_M_QUARTS 0, 9, 6 -- unused
#define FR_M_PILE 6, 9, 4

bool FrenchClockFace::stateForTime(int hour, int minute, int second, bool show_ampm)
{
  if (hour == _hour && minute == _minute)
  {
    return false;
  }

  DLOGLN("update state fr");

  clearDisplay();
  _hour = hour;
  _minute = minute;

  int leftover = minute % 5;
  minute = minute - leftover;

  if (minute >= 35)
    hour = (hour + 1) % 24; // Switch to "TO" minutes the next hour

  updateSegment(FR_S_IL);
  updateSegment(FR_S_EST);

  switch (hour)
  {
  case 0:
    updateSegment(FR_H_MINUIT);
    break;
  case 1:
  case 13:
    updateSegment(FR_H_UNE);
    break;
  case 2:
  case 14:
    updateSegment(FR_H_DEUX);
    break;
  case 3:
  case 15:
    updateSegment(FR_H_TROIS);
    break;
  case 4:
  case 16:
    updateSegment(FR_H_QUATRE);
    break;
  case 5:
  case 17:
    updateSegment(FR_H_CINQ);
    break;
  case 6:
  case 18:
    updateSegment(FR_H_SIX);
    break;
  case 7:
  case 19:
    updateSegment(FR_H_SEPT);
    break;
  case 8:
  case 20:
    updateSegment(FR_H_HUIT);
    break;
  case 9:
  case 21:
    updateSegment(FR_H_NEUF);
    break;
  case 10:
  case 22:
    updateSegment(FR_H_DIX);
    break;
  case 11:
  case 23:
    updateSegment(FR_H_ONZE);
    break;
  case 12:
    updateSegment(FR_H_MIDI);
    break;
  default:
    DLOG("Invalid hour ");
    DLOGLN(hour);
  }
  switch (hour)
  {
  case 0:
  case 12:
    break;
  case 1:
  case 13:
    updateSegment(FR_H_HEURE);
    break;
  default:
    updateSegment(FR_H_HEURES);
    break;
  }

  switch (minute)
  {
  case 0:
    break;
  case 5:
    updateSegment(FR_M_CINQ);
    break;
  case 10:
    updateSegment(FR_M_DIX);
    break;
  case 15:
    updateSegment(FR_M_ET);
    updateSegment(FR_M_QUART);
    break;
  case 20:
    updateSegment(FR_M_VINGT);
    break;
  case 25:
    updateSegment(FR_M_VINGTCINQ);
    break;
  case 30:
    #ifdef FR_ALT
    updateSegment(FR_M_ET2);
    #else
    updateSegment(FR_M_ET);
    #endif
    updateSegment(FR_M_DEMI);
    break;
  case 35:
    updateSegment(FR_M_MOINS);
    updateSegment(FR_M_VINGTCINQ);
    break;
  case 40:
    updateSegment(FR_M_MOINS);
    updateSegment(FR_M_VINGT);
    break;
  case 45:
    updateSegment(FR_M_MOINS);
    updateSegment(FR_M_LE);
    updateSegment(FR_M_QUART);
    break;
  case 50:
    updateSegment(FR_M_MOINS);
    updateSegment(FR_M_DIX);
    break;
  case 55:
    updateSegment(FR_M_MOINS);
    updateSegment(FR_M_CINQ);
    break;
  default:
    DLOG("Invalid minute ");
    DLOGLN(minute);
  }

  switch (leftover)
  {
  case 4:
    _state[mapMinute(TopLeft)] = true;
  case 3: // fall through
    _state[mapMinute(BottomLeft)] = true;
  case 2: // fall through
    _state[mapMinute(BottomRight)] = true;
  case 1: // fall through
    _state[mapMinute(TopRight)] = true;
  case 0: // fall through
    break;
  }
  return true;
}

// Constants to match the EnglishClockFace.
//
// Letters in lowercase below are not used by the clock.
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

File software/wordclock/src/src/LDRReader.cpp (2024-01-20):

#include <Arduino.h>

#include "LDRReader.h"
#include "logging.h"

LDRReader::LDRReader(int pinNumber, float reactionSpeed, int sensitivity)
    : _pin(pinNumber), _reactionSpeed(reactionSpeed), sensitivity(sensitivity)
{
  DCHECK(reactionSpeed <= 1.0, "Too much");
  DCHECK(reactionSpeed > 0, "Not enough");
}

void LDRReader::setup()
{
  pinMode(_pin, INPUT);
  _currentLDR = analogRead(_pin); // Initial value.
}

void LDRReader::loop()
{
  _currentLDR = analogRead(_pin) * _reactionSpeed +
                _currentLDR * (1 - _reactionSpeed);
  DCHECK(_currentLDR <= 4095.0, _currentLDR);
  DCHECK(_currentLDR >= 0.0, _currentLDR);
}

float LDRReader::reading()
{
  if (sensitivity == 0)
  {
    return 0.;
  }
  return min(pow(_currentLDR / 4095.0, 1 / (float)sensitivity), 1.0);
}

uint16_t LDRReader::readingRaw()
{
  return analogRead(_pin);
}

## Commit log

2021-01-12 Add a couple of pictures of a wordclock build
2021-01-12 Added schematic and documentation for the electronics section
    [wordclock.fzz]
2021-01-12 Fix a couple of typos
2021-01-13 Add frame templates and instructions
2021-01-13 Add diagram for LED matrix
2021-01-13 Typos in frame doc
2021-01-13 Add faceplate instructions and files, add final assembly steps
2023-12-02 Update Timer.cpp
    Prevent crash on ESP32C3
2024-01-07 [Build] Change board definition
    Otherone did not work for everybody.
2024-01-08 Add support for Nodo V1.0 board
2024-01-09 Update ClockFace.cpp to avoid compiler warnings
    [ClockFace.cpp]
2024-01-09 Detach timer interrupt on stop.
2024-01-12 Dynamically switch clockface language from the web UI
2024-01-16 Use SNTP directly, remove timer.
2024-01-19 refine mqtt topics and features (wordclock/light/switch, wordclock/light/color, wordclock/sensor/ldr)
2024-02-21 Adding experimental control of the led matrix via mqtt and http api. Expected payload in the format https://codepen.io/t0m/pen/NWJmWry
2024-10-13 Text scroll tweaks and bugfixes. Show IP address upon connexion. Fixes #47, #42. Also clean up PIO environments.
    [ClockFace.cpp]
2024-10-13 avoid converting int to null
    [ClockFace.cpp]
2024-10-16 Dim the color palette on nodo boards
